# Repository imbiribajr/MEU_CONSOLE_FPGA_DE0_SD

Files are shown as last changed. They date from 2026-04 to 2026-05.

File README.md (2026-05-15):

# MEU_CONSOLE_FPGA_DE0_SD

Console de games em FPGA baseado em **Nios II**, com **launcher residente em flash NOR**, jogos carregados a partir de **cartão SD**, entrada por **teclado PS/2** e suporte a controle via **UART/Bluetooth**.

English version: [README.en.md](./README.en.md)

O projeto foi desenvolvido para a família **Intel/Altera Cyclone III** usando **Quartus II 13.0 SP1** e **Nios II EDS 13.0 SP1**. O hardware integra CPU Nios II, SDRAM, interface PS/2, UART, SPI para SD card, controlador de flash paralela e saída para matriz de LED.

## Visao Geral

Ao energizar a placa:

1. a FPGA carrega o hardware
2. o Nios II inicia um bootloader mínimo em memória on-chip
3. esse bootloader lê o `launcher` gravado na flash NOR
4. o `launcher` sobe em SDRAM
5. o `launcher` monta FAT32 no cartão SD
6. os jogos `.gmod` são listados no menu
7. o jogo selecionado é carregado para SDRAM e executado

## Principais Recursos

- Boot autônomo do sistema sem depender de `nios2-download`
- `launcher` persistido em flash paralela
- Jogos armazenados no SD em formato `.gmod`
- Navegacão por teclado **PS/2**
- Controle alternativo via **UART** para módulo Bluetooth/controller serial
- Renderização em **matriz LED HUB75**
- Uso de **SDRAM** para execução do launcher e dos jogos
- Infraestrutura para atualizar launcher, boot e jogos separadamente

## Fotos

Pac-Man rodando na matriz LED com a placa em primeiro plano:

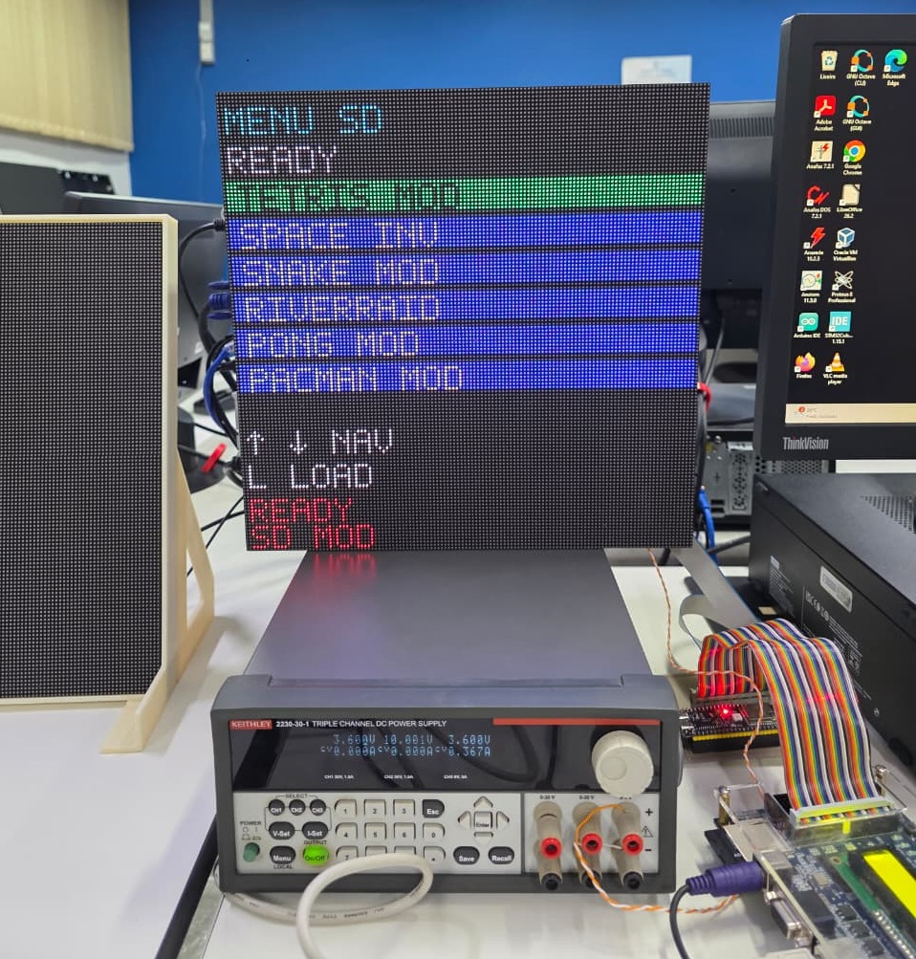
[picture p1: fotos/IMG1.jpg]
Plataforma matriz LED


Launcher em execução com seleção de jogos no SD e controle Bluetooth via UART:

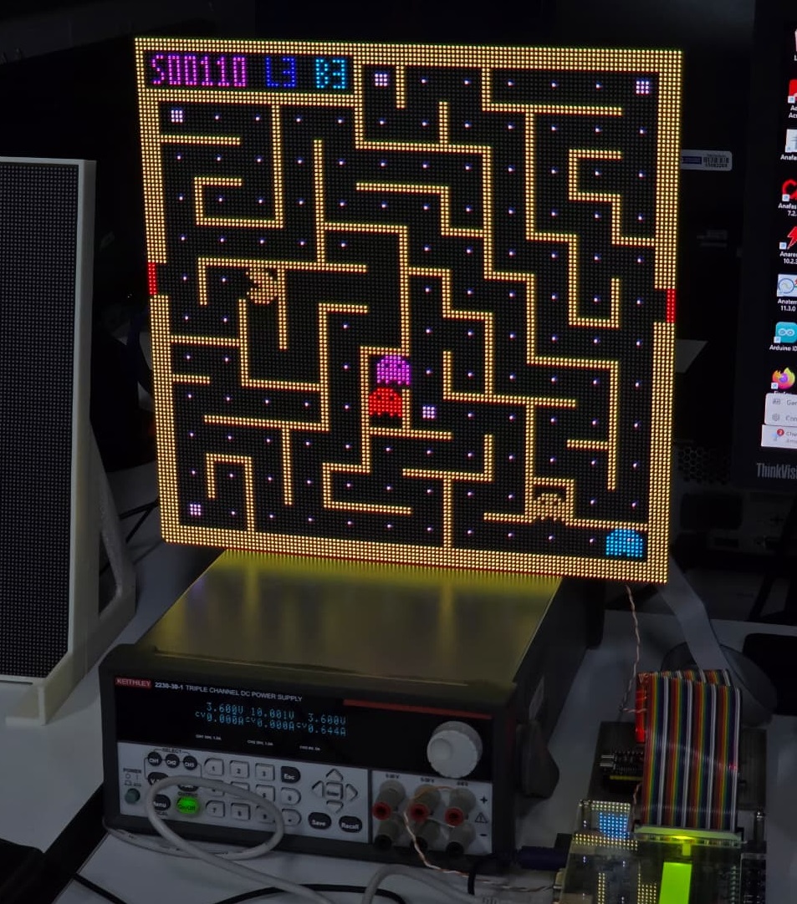
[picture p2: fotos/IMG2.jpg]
Launcher com controle Bluetooth


## Hardware

O hardware principal está em [`hardware/`](./hardware) e usa como topo o arquivo [`hardware/Hardware.vhd`](./hardware/Hardware.vhd).

Blocos relevantes presentes no projeto:

- **Nios II Qsys** gerado em `hardware/NiosII_ps2/`
- **PS/2** via `ps2_avalon_interface.vhd`
- **UART** para recepção de comandos seriais/Bluetooth
- **SPI SD card** para leitura dos jogos no SD
- **Flash NOR paralela** para armazenamento do launcher
- **SDRAM** como memória principal de execução
- **Matriz LED** controlada por `led_matrix_avalon.vhd`

Projeto Quartus:

- arquivo de projeto: [`hardware/DriverVHDL.qpf`](./hardware/DriverVHDL.qpf)
- constraints e pinagem: [`hardware/DriverVHDL.qsf`](./hardware/DriverVHDL.qsf)

## Arquitetura De Software

O software está organizado em três camadas principais:

- **flashboot**
  Bootloader mínimo executado a partir da memória on-chip. Carrega o launcher da NOR para SDRAM.
- **flashwrite**
  Aplicativo utilitário que grava ou atualiza a imagem do launcher na flash paralela.
- **launcher**
  Menu principal que monta FAT32 no SD, lista os jogos e carrega arquivos `.gmod`.

Pastas principais:

- [`software/bsp/`](./software/bsp): BSP gerado pelo Nios II EDS
- [`software/games/flashboot/`](./software/games/flashboot): bootloader
- [`software/games/flashwrite/`](./software/games/flashwrite): gravação da imagem do launcher na NOR
- [`software/games/launcher/`](./software/games/launcher): launcher e módulos de jogo
- [`software/scripts/`](./software/scripts): scripts auxiliares de build e programação
- [`software/workspace/`](./software/workspace): área de app Nios usada no fluxo de desenvolvimento

## Fluxo De Boot

Fluxo validado no projeto:

1. o Nios II sai do reset na memória on-chip
2. o `flashboot` é executado
3. a flash NOR é estabilizada e colocada em `read array`
4. o header `LNCH` do launcher é validado
5. o payload do launcher é copiado para SDRAM
6. `gp`, `sp` e `entry` são ajustados
7. a execução é transferida ao launcher
8. o launcher monta o SD FAT32 e lista os jogos

Documentação de apoio:

- [`software/games/flashboot/BOOT_FLOW.md`](./software/games/flashboot/BOOT_FLOW.md)
- [`software/games/flashboot/README.md`](./software/games/flashboot/README.md)
- [`software/games/flashwrite/README.md`](./software/games/flashwrite/README.md)

## Formato Dos Jogos

Os jogos atuais no SD usam arquivos binários `.gmod`.

Características do formato atual:

- múltiplos segmentos carregáveis
- `entry_addr`, `stack_addr` e `gp_addr` no cabeçalho
- carga direta em SDRAM pelo launcher

Definições:

- [`software/games/launcher/app/launcher_image.h`](./software/games/launcher/app/launcher_image.h)
- gerador: [`software/scripts/gerar_gmod.ps1`](./software/scripts/gerar_gmod.ps1)

Jogos atualmente presentes no repositório:

- Arkanoid
- Boulder Dash (`gdash`)
- Pac-Man
- Pong
- River Raid
- Snake
- Space Invaders
- Tetris

Os binários prontos de exemplo estão em:

- [`software/games/launcher/app/gmods/`](./software/games/launcher/app/gmods)

## Controles

O launcher aceita entrada por:

- **PS/2**
- **UART**
- botões locais mapeados no PIO

No launcher, o mapeamento principal é:

- `Up/Down`: navegar no menu
- `L`, `Enter`, `Space` ou equivalente serial: selecionar/carregar

Nos jogos, o código mostra leitura combinada de:

- scan codes de **PS/2**
- bytes recebidos pela **UART**

Isso permite usar teclado PS/2 ou um controle Bluetooth que entrega comandos seriais à UART do sistema.

A qualquer momento o sistema aceita os seguintes comandos:

- sw0 na DE0 reset o game
- button2 na DE0 recarrega o launcher. Permite o usuário chamar o launcher para carregar novo game

## Como Compilar

### Requisitos

- Quartus II **13.0 SP1**
- Nios II EDS **13.0 SP1**
- Windows com acesso ao `Nios_Shell.bat`
- Cabo **USB-Blaster**

Caminhos usados nos scripts atuais:

- `F:\altera\13.0sp1\quartus`
- `F:\altera\13.0sp1\nios2eds`

Se sua instalação estiver em outro local, ajuste os `.bat` e `.ps1` em [`software/scripts/`](./software/scripts) e nas configurações do VS Code em [`.vscode/settings.json`](./.vscode/settings.json).

### Hardware

Gerar Qsys:

```powershell
cd software\scripts
.\Generate_Qsys.bat
```

Sintetizar no Quartus:

```powershell
cd hardware
quartus_sh --flow compile DriverVHDL
```

Gravar FPGA:

```powershell
cd hardware\output_files
quartus_pgm -m jtag -c USB-Blaster -o "p;DriverVHDL.sof"
```

### BSP

Regenerar arquivos do BSP:

```powershell
cd software\bsp
nios2-bsp-generate-files --settings=settings.bsp --bsp-dir=.
```

Compilar BSP:

```powershell
cd software\scripts
.\compila_BSP.bat
```

### Launcher

Compilar e baixar o launcher para desenvolvimento:

```powershell
cd software\games\launcher\app
.\compila_grava.bat
```

### Geração da Imagem Do Launcher Para Flash

```powershell
powershell -ExecutionPolicy Bypass -File software\scripts\gerar_launcher_flash_image.ps1
```

Esse script gera:

- `software/games/launcher/app/launcher_flash.img`
- `software/games/flashwrite/app/launcher_flash_payload.h`

### Gravar O Launcher Na NOR

Depois de gerar a imagem:

1. compile o `flashwrite`
2. execute o `flashwrite` na placa
3. ele apaga, grava e verifica a imagem na flash

Documentação:

- [`software/games/flashwrite/README.md`](./software/games/flashwrite/README.md)

### Atualizar O Bootloader On-Chip

Sempre que o `flashboot` mudar:

1. compile `software/games/flashboot/app`
2. gere `hardware/onchip_mem.hex`
3. recompile o hardware Quartus para embutir o novo HEX no bitstream

Fluxo detalhado:

- [`software/games/flashboot/BOOT_FLOW.md`](./software/games/flashboot/BOOT_FLOW.md)

## Como Gerar Um Novo Jogo `.gmod`

Cada jogo externo possui um módulo próprio em:

- `software/games/launcher/app/<nome>_module/`

Normalmente cada módulo contém:

- `main.c`
- `external_main.c`
- `build_external.bat`

Exemplo de build de um jogo:

```powershell
cd software\games\launcher\app\pacman_module
.\build_external.bat
```

O `.gmod` resultante e salvo em:

- [`software/games/launcher/app/gmods/`](./software/games/launcher/app/gmods)

Documentação:

- [`software/games/launcher/EXTERNAL_BUILD.md`](./software/games/launcher/EXTERNAL_BUILD.md)

## Estrutura Do Repositório

```text
MEU_CONSOLE_FPGA_DE0_SD/
|- hardware/                      -> projeto Quartus e componentes HDL
|- software/
|  |- bsp/                        -> BSP do Nios II
|  |- games/
|  |  |- flashboot/               -> bootloader em on-chip
|  |  |- flashwrite/              -> gravação da imagem do launcher na NOR
|  |  |- launcher/                -> launcher e jogos
|  |- scripts/                    -> automação de build, flash e geração de imagens
|  |- workspace/                  -> app/workspace de desenvolvimento
|- .vscode/                       -> tasks e botões de ação do VS Code
```

## VS Code

O repositório inclui configuração para trabalhar com VS Code:

- botões de açao em [`.vscode/settings.json`](./.vscode/settings.json)
- tasks em [`.vscode/tasks.json`](./.vscode/tasks.json)
- debug em [`.vscode/launch.json`](./.vscode/launch.json)

O fluxo foi preparado para chamar o ambiente da Intel/Altera via `Nios_Shell.bat`.

## Estado Atual Do Projeto

Pelo estado atual do repositório:

- o hardware Quartus está presente e compilável
- o `flashboot` está integrado ao fluxo de boot
- o `launcher` carrega imagens `.gmod` do SD
- a leitura de FAT32 está implementada no próprio launcher
- os jogos já possuem módulos e artefatos `.gmod`
- o controle por PS/2 e UART está presente no launcher e nos jogos

## Observações

- O projeto inclui arquivos gerados do Qsys/synthesis que fazem parte do fluxo atual.
- Artefatos pesados de compilação do Quartus e objetos temporários do Nios estão filtrados pelo [`.gitignore`](./.gitignore).
- Alguns documentos internos ainda refletem fases anteriores do desenvolvimento; este README descreve o fluxo validado a partir do estado atual do código.

## Licença

Este projeto usa a licença [MIT](./LICENSE).

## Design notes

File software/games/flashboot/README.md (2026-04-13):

# Flashboot

Bootloader minimo que roda na on-chip e carrega o `launcher` da NOR para SDRAM.

## Estado Atual

Fluxo validado:

1. o Nios II sai do reset real em `0x0180C000`
2. o stub em `.reset` salta para `_start`
3. o `flashboot` roda na `onchip_memory2_0`
4. mostra `LOADING...`
5. espera a NOR estabilizar no power-on
6. forca `read array` com `0xF0`
7. le e valida o header `LNCH`
8. copia o payload do `launcher` para SDRAM
9. ajusta `gp/sp`
10. salta para `entry`

## Endereco Da Imagem Na NOR

O `flashboot` atual espera o `launcher` em:

- `FLASHBOOT_IMAGE_OFFSET = 0x010000`

## Arquivos Principais

- [main.c](./app/main.c)
- [linker_flashboot.x](./app/linker_flashboot.x)
- [flashboot_image.h](./app/flashboot_image.h)

## Scripts Relacionados

- gerar imagem do launcher:
  [gerar_launcher_flash_image.ps1](../../scripts/gerar_launcher_flash_image.ps1)
- gerar `onchip_mem.hex`:
  [gerar_onchip_hex.bat](./app/gerar_onchip_hex.bat)

## Documentacao Completa

- [BOOT_FLOW.md](./BOOT_FLOW.md)

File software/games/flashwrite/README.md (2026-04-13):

# Flashwrite

Aplicativo utilitario para gravar a imagem `LNCH` do `launcher` na NOR.

## Fluxo Atual

1. gerar a imagem do launcher:
   - `software/scripts/gerar_launcher_flash_image.ps1`
2. isso atualiza:
   - `software/games/flashwrite/app/launcher_flash_payload.h`
3. compilar o `flashwrite`:
   - `software/games/flashwrite/app/compila_grava.bat`
4. executar o `flashwrite`
5. o app:
   - apaga
   - programa
   - verifica

## Mapeamento Validado

No fluxo final estabilizado:

- a imagem do launcher e gravada a partir de `0x010000`
- a geometria efetiva tratada pelo software usa setores de `0x8000`
- o espaco efetivo usado pelo software ficou em `2 MB`

## Arquivos Principais

- [main.c](./app/main.c)
- [launcher_flash_payload.h](./app/launcher_flash_payload.h)

## Relacao Com O Boot

Depois de gravar a NOR com sucesso, o `flashboot` pode carregar o `launcher` automaticamente no power-on.

Fluxo completo:

- [BOOT_FLOW.md](../flashboot/BOOT_FLOW.md)

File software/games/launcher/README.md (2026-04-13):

# Launcher

Launcher principal da plataforma.

## Arquitetura Atual

No fluxo final validado:

1. o `flashboot` sobe da on-chip
2. o `launcher` e carregado da NOR para SDRAM
3. o `launcher` monta FAT32 no SD
4. o menu enumera os jogos em `games/*.gmod`
5. o `launcher` carrega a imagem externa para SDRAM e salta para o jogo

## Formato De Jogo No SD

Os jogos no SD sao armazenados como arquivos binarios `.gmod`.

Campos principais:

- `version = 2`
- `segment_count`
- `entry_addr`
- `stack_addr`
- `gp_addr`
- `header_size`
- `title[32]`

Depois do cabecalho vem a tabela de segmentos e o payload binario.

## Geracao Dos `.gmod`

O fluxo correto nao usa mais diretamente o `main.elf` standalone antigo de desenvolvimento.

O `.gmod` final deve ser gerado a partir dos modulos de producao em:

- `software/games/launcher/app/*_module/`

Cada jogo externo usa:

- `main.c`
- `external_main.c`
- `build_external.bat`

Os `.gmod` gerados ficam em:

- `software/games/launcher/app/gmods/`

Documentacao detalhada:

- [EXTERNAL_BUILD.md](./EXTERNAL_BUILD.md)

## Arquivos Principais

- [main.c](./app/main.c)
- [launcher_image.h](./app/launcher_image.h)
- [launcher_storage_stub.c](./app/launcher_storage_stub.c)

## Relacao Com O Boot

O fluxo de boot automatico completo foi consolidado em:

- [BOOT_FLOW.md](../flashboot/BOOT_FLOW.md)

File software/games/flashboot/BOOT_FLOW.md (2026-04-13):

# Boot Flow Do Launcher

Este documento descreve a cadeia real de boot da plataforma, do power-on ate o launcher aparecer no display.

## Objetivo

Ao ligar a placa:

1. a FPGA configura o hardware
2. o Nios II entra no `flashboot`
3. o `flashboot` carrega o `launcher` da flash paralela para a SDRAM
4. o `launcher` sobe
5. o `launcher` lista e executa os jogos do SD

## Blocos Do Sistema

- `launcher`
  Menu principal. Roda em SDRAM e carrega jogos binarios `.gmod` do SD.

- `flashwrite`
  Aplicativo utilitario que grava a imagem empacotada do `launcher` no inicio da flash paralela.

- `flashboot`
  Bootloader minimo que roda na `onchip_memory2_0`, le a imagem do `launcher` da flash paralela, copia para SDRAM e transfere a execucao.

## Estado Validado

### Flash paralela

A flash paralela conectada ao `generic_tristate_controller_0` em `0x01400000` foi validada:

- leitura simples OK
- `CFI QRY` OK
- erase OK
- program OK
- readback OK

Conclusao: a interface com a NOR esta funcional.

### Launcher

O `launcher` ja esta funcional:

- inicializa a plataforma
- acessa o SD
- monta FAT32
- enumera jogos
- mostra o menu no display
- executa jogos binarios do SD e ainda aceita descritores texto legados como fallback

### Flashboot

O `flashboot` ja foi validado manualmente com `nios2-download -g`:

- ele le a imagem da flash
- copia o payload para SDRAM
- ajusta `gp` e `sp`
- salta para o `entry`
- o `launcher` sobe corretamente

## Ponto Critico Descoberto

O boot automatico falhava por dois motivos distintos.

### 1. Diferenca entre reset real e entry point do ELF

No boot real, o Nios II comeca no reset vector configurado no hardware:

- `0x0180C000`

No `nios2-download -g`, a execucao comeca no `_start` do ELF:

- `0x0180C040`

Sem um codigo explicito em `0x0180C000`, o power-on nao chegava ao `flashboot`, mesmo com o ELF correto.

### 2. Flash paralela ainda nao pronta no power-on

Depois que o stub de reset foi corrigido, ainda havia falha no power-on porque a NOR podia nao estar pronta na primeira leitura logo apos a configuracao da FPGA.

Isso foi resolvido no `flashboot` com:

- atraso inicial curto
- comando `0xF0` para forcar `read array`
- retries de leitura/validacao do header

Conclusao: o boot automatico correto depende tanto do stub de reset quanto da robustez na primeira leitura da NOR.

## Fluxo Real De Boot

Sequencia completa:

1. a FPGA carrega o bitstream
2. a `onchip_memory2_0` sobe inicializada com `onchip_mem.hex`
3. o Nios II sai do reset em `0x0180C000`
4. o stub em `.reset` salta para `_start`
5. o `flashboot` inicializa o display e mostra `LOADING...`
6. o `flashboot` espera a NOR estabilizar
7. o `flashboot` envia `0xF0` para garantir `read array`
8. o `flashboot` le e valida o header `LNCH` na flash
9. o `flashboot` copia o payload do `launcher` para SDRAM
10. o `flashboot` ajusta `gp` e `sp`
11. o `flashboot` salta para o `entry` do `launcher`
12. o `launcher` sobe e passa a operar normalmente

## Enderecos Importantes

- flash paralela:
  `GENERIC_TRISTATE_CONTROLLER_0_BASE = 0x01400000`

- on-chip do boot:
  `ONCHIP_MEMORY2_0_BASE = 0x0180C000`

- reset real do Nios II:
  `NIOS2_RESET_ADDR = 0x0180C000`

- exception vector:
  `NIOS2_EXCEPTION_ADDR = 0x0180C020`

- `_start` atual do `flashboot`:
  `0x0180C040`

## Arquitetura Da Imagem Na Flash

O `flashboot` espera uma imagem `LNCH` no inicio da flash paralela.

Header:

```c
typedef struct flashboot_image_header {
    uint32_t magic;
    uint32_t version;
    uint32_t load_addr;
    uint32_t entry_addr;
    uint32_t gp_addr;
    uint32_t sp_addr;
    uint32_t payload_size;
    uint32_t payload_checksum;
} flashboot_image_header_t;
```

Campos principais:

- `magic = 'LNCH'`
- `version = 1`
- `load_addr = endereco de carga do launcher na SDRAM`
- `entry_addr = entry do launcher`
- `gp_addr = gp do launcher`
- `sp_addr = sp do launcher`
- `payload_size = tamanho do binario`
- `payload_checksum = soma simples dos bytes`

Depois do header vem o payload bruto do `launcher`.

## Cadeia Necessaria Para O Launcher Correto

Para o boot automatico funcionar de forma consistente, toda a cadeia abaixo precisa estar alinhada.

### 1. Launcher compilado

O `launcher` precisa ser compilado normalmente.

Artefato principal:

- `software/games/launcher/app/main.elf`

### 2. Imagem LNCH gerada

O script:

- [gerar_launcher_flash_image.ps1](../../scripts/gerar_launcher_flash_image.ps1)

gera:

- [launcher_flash.img](../launcher/app/launcher_flash.img)
- [launcher_flash_payload.h](../flashwrite/app/launcher_flash_payload.h)

Essa imagem precisa corresponder ao `launcher` que voce quer subir no boot.

### 3. Launcher gravado na flash paralela

O `flashwrite` usa:

- [main.c](../flashwrite/app/main.c)
- [launcher_flash_payload.h](../flashwrite/app/launcher_flash_payload.h)

para:

1. apagar os setores iniciais
2. programar a imagem `LNCH`
3. verificar byte a byte

O resultado esperado e:

- `flashwrite: OK`

### 4. Flashboot compilado com stub de reset

O `flashboot` precisa conter o stub explicito em `.reset`:

```c
void flashboot_reset_stub(void) __attribute__((section(".reset"), naked));
void flashboot_reset_stub(void)
{
    __asm__ __volatile__(
        "movia r2, _start\n"
        "jmp r2\n"
    );
}
```

Esse stub garante que o boot real iniciado em `0x0180C000` chegue ao `_start`.

### 5. Linker do flashboot apontando para a on-chip

O linker do `flashboot` precisa manter:

- memoria `onchip` com origem em `0x0180C000`
- secao `.reset` mantida no inicio dessa memoria

Arquivo:

- [linker_flashboot.x](./app/linker_flashboot.x)

### 6. Robustez de power-on na leitura da NOR

O `flashboot` validado agora contem:

- atraso inicial de power-up
- `flash_reset_read_array()`
- retries de leitura/validacao do header

Isso e necessario porque o boot real ocorre imediatamente apos a configuracao, ao contrario do `nios2-download`.

### 7. `onchip_mem.hex` gerado a partir do flashboot correto

Depois de compilar o `flashboot`, e preciso gerar:

- [hardware/onchip_mem.hex](../../../hardware/onchip_mem.hex)

com:

- [gerar_onchip_hex.bat](./app/gerar_onchip_hex.bat)

Esse passo tambem atualiza:

- [NiosII_ps2_onchip_memory2_0.hex](../../../hardware/NiosII_ps2/synthesis/submodules/NiosII_ps2_onchip_memory2_0.hex)

### 8. Hardware recompilado usando esse HEX

O Qsys precisa continuar apontando para:

- `resetSlave = onchip_memory2_0.s1`
- `exceptionSlave = onchip_memory2_0.s1`
- `initializationFileName = onchip_mem.hex`

Depois disso, o hardware Quartus precisa ser recompilado para embutir o novo conteudo da on-chip no bitstream.

### 9. Bitstream final gravado na FPGA / serial flash

O `.sof` ou `.pof` final precisa conter:

- o hardware atual
- o `onchip_mem.hex` gerado a partir do `flashboot` correto

Sem esse passo, a placa pode continuar iniciando com um `flashboot` antigo mesmo que a NOR ja tenha sido atualizada.

## Sequencia Operacional Correta

Use esta ordem quando quiser atualizar o boot completo da plataforma.

### 1. Recompilar o launcher

No PowerShell:

```powershell
cd F:\Jogos_FPGA\MEU_CONSOLE_FPGA_DE0_SD\software\games\launcher\app
.\compila_grava.bat
```

### 2. Regenerar a imagem do launcher para a NOR

```powershell
powershell -ExecutionPolicy Bypass -File "F:\Jogos_FPGA\MEU_CONSOLE_FPGA_DE0_SD\software\scripts\gerar_launcher_flash_image.ps1"
```

Isso atualiza:

- `software/games/launcher/app/launcher_flash.img`
- `software/games/flashwrite/app/launcher_flash_payload.h`

### 3. Recompilar o flashwrite

```powershell
cd F:\Jogos_FPGA\MEU_CONSOLE_FPGA_DE0_SD\software\games\flashwrite\app
.\compila_grava.bat
```

### 4. Gravar a NOR com o launcher

Execute o `flashwrite` e espere terminar com:

- `flashwrite: OK`

No fluxo atual validado, o `launcher` e gravado a partir de:

- `0x010000`

### 5. Recompilar o flashboot

```powershell
cd F:\Jogos_FPGA\MEU_CONSOLE_FPGA_DE0_SD\software\games\flashboot\app
.\compila_grava.bat
```

### 6. Regenerar o onchip_mem.hex

Ainda dentro de `flashboot/app`:

```powershell
.\gerar_onchip_hex.bat
```

### 7. Recompilar o hardware no Quartus

Depois do `onchip_mem.hex` novo, recompile o projeto Quartus para embutir o `flashboot` atualizado na on-chip.

### 8. Carregar o .sof novo na FPGA

Para teste rapido, basta gravar o `.sof` novo por JTAG. Nao e necessario gravar o `.pof` ainda.

### 9. Preparar o SD

No SD devem estar:

- os jogos `.gmod` binarios reais em `games/`

O `launcher` nao precisa ir para o SD nesse fluxo, porque ele ja esta na NOR.

Observacao importante sobre os jogos:

- o `.gmod` binario deve ser gerado a partir de um ELF compativel com o ambiente do `launcher`
- nao use diretamente o ELF standalone de desenvolvimento sem validar compatibilidade
- a base mais segura para gerar esses ELFs e o codigo ja adaptado dentro de:
  - `software/games/launcher/app/pacman_module/`
  - `software/games/launcher/app/tetris_module/`
  - e equivalentes para outros jogos
- em outras palavras, o `main.c` usado como entrada de compilacao para o ELF externo deve vir das pastas `*_module` do `launcher`, ou de uma versao externa derivada delas, e nao do fluxo antigo de desenvolvimento isolado

### 10. Testar o power-on

Fluxo esperado:

1. a FPGA sobe com o `flashboot` novo
2. o `flashboot` le o `launcher` em `0x010000` da NOR
3. o `launcher` sobe
4. o `launcher` carrega os jogos do SD

### 11. So depois gerar/gravar o .pof

Se o teste com `.sof` por JTAG funcionar, ai sim faz sentido fechar o processo com o `.pof` definitivo na serial flash.

Nao basta gerar o novo `onchip_mem.hex`.

E preciso garantir que o `.sof` ou `.pof` realmente gravado na placa foi gerado depois dessa atualizacao.

Se o arquivo de configuracao gravado for antigo, o Nios continuara usando uma on-chip antiga no power-on.

## Sequencia Pratica Recomendada

Fluxo completo para fechar o launcher correto:

1. compilar o `launcher`
2. rodar `gerar_launcher_flash_image.ps1`
3. gravar a imagem do `launcher` na NOR com `flashwrite`
4. compilar o `flashboot`
5. rodar `gerar_onchip_hex.bat`
6. recompilar o hardware Quartus
7. gerar o `.sof` ou `.pof`
8. gravar o arquivo final de configuracao na FPGA ou serial flash
9. energizar a placa e observar `LOADING...`
10. confirmar a subida automatica do `launcher`

## Diagnostico Esperado

### Se tudo estiver correto

No power-on:

- `LOADING...` aparece imediatamente
- o `launcher` sobe sem `nios2-download`

### Se `LOADING...` nao aparecer

O problema tende a estar antes do acesso a flash:

- bitstream antigo
- `onchip_mem.hex` antigo embutido no hardware
- reset vector nao atingindo o `flashboot`

### Se `LOADING...` aparecer mas o launcher nao subir

O problema tende a estar depois da entrada no `flashboot`:

- imagem `LNCH` nao gravada corretamente
- header invalido
- payload inconsistente
- falha de leitura da NOR

## Atualizacao De Jogos Depois Disso

Modelo desejado:

- flash paralela guarda o `launcher`
- SD guarda os jogos

Entao:

- mudar jogo no SD nao exige reflashing da NOR
- mudar o `launcher` exige regenerar a imagem e regravar a NOR

## Arquivos Principais

### Flashboot

- [main.c](./app/main.c)
- [flashboot_image.h](./app/flashboot_image.h)
- [linker_flashboot.x](./app/linker_flashboot.x)
- [gerar_onchip_hex.bat](./app/gerar_onchip_hex.bat)

### Gravacao Da NOR

- [main.c](../flashwrite/app/main.c)
- [launcher_flash_payload.h](../flashwrite/app/launcher_flash_payload.h)
- [gerar_launcher_flash_image.ps1](../../scripts/gerar_launcher_flash_image.ps1)

### Launcher

- [main.c](../launcher/app/main.c)

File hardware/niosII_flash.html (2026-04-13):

niosII_flash

2026.03.27.23:20:15 | Datasheet

Overview

clk_0 | niosII_flash

clk_audio

Processor
nios2_qsys_0 Nios II 13.0
All Components
nios2_qsys_0 altera_nios2_qsys 13.0
onchip_memory2_0 altera_avalon_onchip_memory2 13.0.1.99.2
jtag_uart_0 altera_avalon_jtag_uart 13.0.1.99.2
pio_0 altera_avalon_pio 13.0.1.99.2
led_matrix_avalon_0 led_matrix_avalon 1.0
sysid_qsys_0 altera_avalon_sysid_qsys 13.0
ps2_interface_0 ps2_interface 1.0
new_sdram_controller_0 altera_avalon_new_sdram_controller 13.0.1.99.2
audio AUDIO_IF 2.0
i2c_clk altera_avalon_pio 13.0.1.99.2
i2c_sda altera_avalon_pio 13.0.1.99.2
timer_0 altera_avalon_timer 13.0.1.99.2
generic_tristate_controller_0 altera_generic_tristate_controller 13.0

Memory Map

| nios2_qsys_0
| data_master | instruction_master
nios2_qsys_0
jtag_debug_module | 0x01810800 | 0x01810800
onchip_memory2_0
s1 | 0x0180c000 | 0x0180c000
jtag_uart_0
avalon_jtag_slave | 0x018110f8 | 0x018110f8
pio_0
s1 | 0x018110d0 | 0x018110d0
led_matrix_avalon_0
avalon_slave | 0x01808000 | 0x01808000
sysid_qsys_0
control_slave | 0x018110f0 | 0x018110f0
ps2_interface_0
avalon_slave_0 | 0x01811104 | 0x01811104
new_sdram_controller_0
s1 | 0x00800000 | 0x00800000
audio
avalon_slave | 0x01811060 | 0x01811060
i2c_clk
s1 | 0x018110c0 | 0x018110c0
i2c_sda
s1 | 0x018110b0 | 0x018110b0
timer_0
s1 | 0x01811040 | 0x01811040
generic_tristate_controller_0
uas | 0x01400000 | 0x01400000

## clk_0

clock_source v13.0

Parameters

clockFrequency | 50000000
clockFrequencyKnown | true
inputClockFrequency | 0
resetSynchronousEdges | NONE
deviceFamily | UNKNOWN
generateLegacySim | false

Software Assignments
(none)

## nios2_qsys_0

altera_nios2_qsys v13.0

clk_0 | clk | nios2_qsys_0
| clk
| clk_reset
| reset_n
| | | instruction_master | onchip_memory2_0
| | | s1
| | | data_master
| | | s1
| | | jtag_debug_module_reset
| | | reset1
| | | data_master | jtag_uart_0
| | | avalon_jtag_slave
| | | d_irq
| | | irq
| | | jtag_debug_module_reset
| | | reset
| | | instruction_master
| | | avalon_jtag_slave
| | | data_master | pio_0
| | | s1
| | | jtag_debug_module_reset
| | | reset
| | | instruction_master
| | | s1
| | | data_master | led_matrix_avalon_0
| | | avalon_slave
| | | jtag_debug_module_reset
| | | reset_n
| | | instruction_master
| | | avalon_slave
| | | data_master | sysid_qsys_0
| | | control_slave
| | | instruction_master
| | | control_slave
| | | jtag_debug_module_reset
| | | reset
| | | data_master | ps2_interface_0
| | | avalon_slave_0
| | | jtag_debug_module_reset
| | | reset
| | | instruction_master
| | | avalon_slave_0
| | | instruction_master | new_sdram_controller_0
| | | s1
| | | data_master
| | | s1
| | | jtag_debug_module_reset
| | | reset
| | | data_master | audio
| | | avalon_slave
| | | instruction_master
| | | avalon_slave
| | | jtag_debug_module_reset
| | clock_sink_reset
| | data_master | i2c_clk
| | s1
| | instruction_master
| | s1
| | jtag_debug_module_reset
| | reset
| | jtag_debug_module_reset | i2c_sda
| | reset
| | instruction_master
| | s1
| | data_master
| | s1
| | jtag_debug_module_reset | clk_audio
| | clk_in_reset
| | jtag_debug_module_reset | timer_0
| | reset
| | instruction_master
| | s1
| | data_master
| | s1
| | d_irq
| | irq
| | jtag_debug_module_reset | generic_tristate_controller_0
| | reset
| | instruction_master
| | uas
| | data_master
| | uas

Parameters

setting_showUnpublishedSettings | false
setting_showInternalSettings | false
setting_preciseSlaveAccessErrorException | false
setting_preciseIllegalMemAccessException | false
setting_preciseDivisionErrorException | false
setting_performanceCounter | false
setting_illegalMemAccessDetection | false
setting_illegalInstructionsTrap | false
setting_fullWaveformSignals | false
setting_extraExceptionInfo | false
setting_exportPCB | false
setting_debugSimGen | false
setting_clearXBitsLDNonBypass | true
setting_bit31BypassDCache | true
setting_bigEndian | false
setting_export_large_RAMs | false
setting_asic_enabled | false
setting_asic_synopsys_translate_on_off | false
setting_oci_export_jtag_signals | false
setting_bhtIndexPcOnly | false
setting_avalonDebugPortPresent | false
setting_alwaysEncrypt | true
setting_allowFullAddressRange | false
setting_activateTrace | true
setting_activateTestEndChecker | false
setting_activateMonitors | true
setting_activateModelChecker | false
setting_HDLSimCachesCleared | true
setting_HBreakTest | false
muldiv_divider | true
mpu_useLimit | false
mpu_enabled | false
mmu_enabled | false
mmu_autoAssignTlbPtrSz | true
manuallyAssignCpuID | true
debug_triggerArming | true
debug_embeddedPLL | true
debug_debugReqSignals | false
debug_assignJtagInstanceID | false
dcache_omitDataMaster | false
cpuReset | false
is_hardcopy_compatible | false
setting_shadowRegisterSets | 0
mpu_numOfInstRegion | 8
mpu_numOfDataRegion | 8
mmu_TLBMissExcOffset | 0
debug_jtagInstanceID | 0
resetOffset | 0
exceptionOffset | 32
cpuID | 0
cpuID_stored | 0
breakOffset | 32
userDefinedSettings
resetSlave | onchip_memory2_0.s1
mmu_TLBMissExcSlave | None
exceptionSlave | onchip_memory2_0.s1
breakSlave | nios2_qsys_0.jtag_debug_module
setting_perfCounterWidth | 32
setting_interruptControllerType | Internal
setting_branchPredictionType | Automatic
setting_bhtPtrSz | 8
muldiv_multiplierType | EmbeddedMulFast
mpu_minInstRegionSize | 12
mpu_minDataRegionSize | 12
mmu_uitlbNumEntries | 4
mmu_udtlbNumEntries | 6
mmu_tlbPtrSz | 7
mmu_tlbNumWays | 16
mmu_processIDNumBits | 8
impl | Fast
icache_size | 4096
icache_tagramBlockType | Automatic
icache_ramBlockType | Automatic
icache_numTCIM | 0
icache_burstType | None
dcache_bursts | false
dcache_victim_buf_impl | ram
debug_level | Level1
debug_OCIOnchipTrace | _128
dcache_size | 2048
dcache_tagramBlockType | Automatic
dcache_ramBlockType | Automatic
dcache_numTCDM | 0
dcache_lineSize | 32
setting_exportvectors | false
setting_ecc_present | false
regfile_ramBlockType | Automatic
ocimem_ramBlockType | Automatic
mmu_ramBlockType | Automatic
bht_ramBlockType | Automatic
resetAbsoluteAddr | 25214976
exceptionAbsoluteAddr | 25215008
breakAbsoluteAddr | 25233440
mmu_TLBMissExcAbsAddr | 0
dcache_bursts_derived | false
dcache_size_derived | 2048
dcache_lineSize_derived | 32
translate_on | "synthesis translate_on"
translate_off | "synthesis translate_off"
instAddrWidth | 25
dataAddrWidth | 25
tightlyCoupledDataMaster0AddrWidth | 1
tightlyCoupledDataMaster1AddrWidth | 1
tightlyCoupledDataMaster2AddrWidth | 1
tightlyCoupledDataMaster3AddrWidth | 1
tightlyCoupledInstructionMaster0AddrWidth | 1
tightlyCoupledInstructionMaster1AddrWidth | 1
tightlyCoupledInstructionMaster2AddrWidth | 1
tightlyCoupledInstructionMaster3AddrWidth | 1

instSlaveMapParam

<address-map><slave name='new_sdram_controller_0.s1' start='0x800000' end='0x1000000' /><slave name='generic_tristate_controller_0.uas' start='0x1400000' end='0x1800000' /><slave name='led_matrix_avalon_0.avalon_slave' start='0x1808000' end='0x180C000' /><slave name='onchip_memory2_0.s1' start='0x180C000' end='0x1810000' /><slave name='nios2_qsys_0.jtag_debug_module' start='0x1810800' end='0x1811000' /><slave name='timer_0.s1' start='0x1811040' end='0x1811060' /><slave name='audio.avalon_slave' start='0x1811060' end='0x1811080' /><slave name='i2c_sda.s1' start='0x18110B0' end='0x18110C0' /><slave name='i2c_clk.s1' start='0x18110C0' end='0x18110D0' /><slave name='pio_0.s1' start='0x18110D0' end='0x18110E0' /><slave name='sysid_qsys_0.control_slave' start='0x18110F0' end='0x18110F8' /><slave name='jtag_uart_0.avalon_jtag_slave' start='0x18110F8' end='0x1811100' /><slave name='ps2_interface_0.avalon_slave_0' start='0x1811104' end='0x1811108' /></address-map>

dataSlaveMapParam

<address-map><slave name='new_sdram_controller_0.s1' start='0x800000' end='0x1000000' /><slave name='generic_tristate_controller_0.uas' start='0x1400000' end='0x1800000' /><slave name='led_matrix_avalon_0.avalon_slave' start='0x1808000' end='0x180C000' /><slave name='onchip_memory2_0.s1' start='0x180C000' end='0x1810000' /><slave name='nios2_qsys_0.jtag_debug_module' start='0x1810800' end='0x1811000' /><slave name='timer_0.s1' start='0x1811040' end='0x1811060' /><slave name='audio.avalon_slave' start='0x1811060' end='0x1811080' /><slave name='i2c_sda.s1' start='0x18110B0' end='0x18110C0' /><slave name='i2c_clk.s1' start='0x18110C0' end='0x18110D0' /><slave name='pio_0.s1' start='0x18110D0' end='0x18110E0' /><slave name='sysid_qsys_0.control_slave' start='0x18110F0' end='0x18110F8' /><slave name='jtag_uart_0.avalon_jtag_slave' start='0x18110F8' end='0x1811100' /><slave name='ps2_interface_0.avalon_slave_0' start='0x1811104' end='0x1811108' /></address-map>
clockFrequency | 50000000
deviceFamilyName | CYCLONEII
internalIrqMaskSystemInfo | 3
customInstSlavesSystemInfo | <info/>

deviceFeaturesSystemInfo

ADDRESS_STALL 1 CELL_LEVEL_BACK_ANNOTATION_DISABLED 0 COMPILER_SUPPORT 1 DSP 0 DSP_SHIFTER_BLOCK 0 DUMP_ASM_LAB_BITS_FOR_POWER 1 EMUL 1 ENABLE_ADVANCED_IO_ANALYSIS_GUI_FEATURES 0 EPCS 1 ESB 0 FAKE1 0 FAKE2 0 FAKE3 0 FAMILY_LEVEL_INSTALLATION_ONLY 1 FITTER_USE_FALLING_EDGE_DELAY 0 GENERATE_DC_ON_CURRENT_WARNING_FOR_INTERNAL_CLAMPING_DIODE 0 HARDCOPY 0 HAS_18_BIT_MULTS 0 HAS_ACE_SUPPORT 1 HAS_ADJUSTABLE_OUTPUT_IO_TIMING_MEAS_POINT 0 HAS_ADVANCED_IO_INVERTED_CORNER 0 HAS_ADVANCED_IO_POWER_SUPPORT 0 HAS_ADVANCED_IO_TIMING_SUPPORT 0 HAS_ALM_SUPPORT 0 HAS_ATOM_AND_ROUTING_POWER_MODELED_TOGETHER 0 HAS_AUTO_DERIVE_CLOCK_UNCERTAINTY_SUPPORT 0 HAS_AUTO_FIT_SUPPORT 1 HAS_BALANCED_OPT_TECHNIQUE_SUPPORT 1 HAS_BENEFICIAL_SKEW_SUPPORT 0 HAS_BITLEVEL_DRIVE_STRENGTH_CONTROL 0 HAS_BSDL_FILE_GENERATION 0 HAS_CGA_SUPPORT 1 HAS_CHECK_NETLIST_SUPPORT 1 HAS_CLOCK_REGION_CHECKER_ENABLED 1 HAS_CORE_JUNCTION_TEMP_DERATING 1 HAS_CROSSTALK_SUPPORT 0 HAS_CUSTOM_REGION_SUPPORT 1 HAS_DAP_JTAG_FROM_HPS 0 HAS_DATA_DRIVEN_ACVQ_HSSI_SUPPORT 0 HAS_DDB_FDI_SUPPORT 0 HAS_DESIGN_ANALYZER_SUPPORT 1 HAS_DETAILED_IO_RAIL_POWER_MODEL 1 HAS_DETAILED_LEIM_STATIC_POWER_MODEL 0 HAS_DETAILED_LE_POWER_MODEL 1 HAS_DETAILED_ROUTING_MUX_STATIC_POWER_MODEL 0 HAS_DETAILED_THERMAL_CIRCUIT_PARAMETER_SUPPORT 1 HAS_DEVICE_MIGRATION_SUPPORT 1 HAS_DIAGONAL_MIGRATION_SUPPORT 0 HAS_EMIF_TOOLKIT_SUPPORT 0 HAS_ERROR_DETECTION_SUPPORT 0 HAS_FAMILY_VARIANT_MIGRATION_SUPPORT 0 HAS_FANOUT_FREE_NODE_SUPPORT 1 HAS_FAST_FIT_SUPPORT 1 HAS_FITTER_EARLY_TIMING_ESTIMATE_SUPPORT 1 HAS_FITTER_ECO_SUPPORT 1 HAS_FIT_NETLIST_OPT_RETIME_SUPPORT 1 HAS_FIT_NETLIST_OPT_SUPPORT 1 HAS_FORMAL_VERIFICATION_SUPPORT 1 HAS_FPGA_XCHANGE_SUPPORT 1 HAS_FSAC_LUTRAM_REGISTER_PACKING_SUPPORT 0 HAS_FULL_DAT_MIN_TIMING_SUPPORT 1 HAS_FULL_INCREMENTAL_DESIGN_SUPPORT 1 HAS_FUNCTIONAL_SIMULATION_SUPPORT 1 HAS_FUNCTIONAL_VERILOG_SIMULATION_SUPPORT 0 HAS_FUNCTIONAL_VHDL_SIMULATION_SUPPORT 0 HAS_GLITCH_FILTERING_SUPPORT 1 HAS_HC_READY_SUPPORT 0 HAS_HIGH_SPEED_LOW_POWER_TILE_SUPPORT 0 HAS_HOLD_TIME_AVOIDANCE_ACROSS_CLOCK_SPINE_SUPPORT 1 HAS_HSPICE_WRITER_SUPPORT 0 HAS_HSSI_POWER_CALCULATOR 0 HAS_IBISO_WRITER_SUPPORT 1 HAS_INCREMENTAL_DAT_SUPPORT 0 HAS_INCREMENTAL_SYNTHESIS_SUPPORT 1 HAS_INTERFACE_PLANNER_SUPPORT 0 HAS_IO_ASSIGNMENT_ANALYSIS_SUPPORT 1 HAS_IO_DECODER 0 HAS_IO_PLACEMENT_OPTIMIZATION_SUPPORT 1 HAS_IO_SMART_RECOMPILE_SUPPORT 1 HAS_JITTER_SUPPORT 0 HAS_JTAG_SLD_HUB_SUPPORT 1 HAS_LIMITED_TCL_FITTER_SUPPORT 0 HAS_LOGIC_LOCK_SUPPORT 1 HAS_MICROPROCESSOR 0 HAS_MIF_SMART_COMPILE_SUPPORT 1 HAS_MINMAX_TIMING_MODELING_SUPPORT 0 HAS_MIN_TIMING_ANALYSIS_SUPPORT 1 HAS_MUX_RESTRUCTURE_SUPPORT 1 HAS_NEW_HC_FLOW_SUPPORT 0 HAS_NEW_SERDES_MAX_RESOURCE_COUNT_REPORTING_SUPPORT 0 HAS_NEW_VPR_SUPPORT 1 HAS_NONSOCKET_TECHNOLOGY_MIGRATION_SUPPORT 0 HAS_NO_HARDBLOCK_PARTITION_SUPPORT 0 HAS_NO_JTAG_USERCODE_SUPPORT 0 HAS_OPERATING_SETTINGS_AND_CONDITIONS_REPORTING_SUPPORT 1 HAS_PAD_LOCATION_ASSIGNMENT_SUPPORT 1 HAS_PARTIAL_RECONFIG_SUPPORT 0 HAS_PHYSICAL_NETLIST_OUTPUT 0 HAS_PHYSICAL_ROUTING_SUPPORT 0 HAS_PIN_SPECIFIC_VOLTAGE_SUPPORT 0 HAS_PLDM_REF_SUPPORT 1 HAS_POWER_ESTIMATION_SUPPORT 1 HAS_PRELIMINARY_CLOCK_UNCERTAINTY_NUMBERS 0 HAS_PRE_FITTER_FPP_SUPPORT 0 HAS_PRE_FITTER_LUTRAM_NETLIST_CHECKER_ENABLED 0 HAS_PVA_SUPPORT 1 HAS_RCF_SUPPORT 1 HAS_RCF_SUPPORT_FOR_DEBUGGING 0 HAS_RED_BLACK_SEPARATION_SUPPORT 0 HAS_RE_LEVEL_TIMING_GRAPH_SUPPORT 0 HAS_RISEFALL_DELAY_SUPPORT 1 HAS_SIGNAL_PROBE_SUPPORT 1 HAS_SIGNAL_TAP_SUPPORT 1 HAS_SIMULATOR_SUPPORT 1 HAS_SPLIT_IO_SUPPORT 0 HAS_SPLIT_LC_SUPPORT 1 HAS_SYNTH_FSYN_NETLIST_OPT_SUPPORT 0 HAS_SYNTH_NETLIST_OPT_RETIME_SUPPORT 1 HAS_SYNTH_NETLIST_OPT_SUPPORT 1 HAS_TCL_FITTER_SUPPORT 0 HAS_TECHNOLOGY_MIGRATION_SUPPORT 0 HAS_TEMPLATED_REGISTER_PACKING_SUPPORT 1 HAS_TIME_BORROWING_SUPPORT 0 HAS_TIMING_DRIVEN_SYNTHESIS_SUPPORT 1 HAS_TIMING_INFO_SUPPORT 1 HAS_TIMING_OPERATING_CONDITIONS 0 HAS_TIMING_SIMULATION_SUPPORT 1 HAS_TITAN_BASED_MAC_REGISTER_PACKER_SUPPORT 0 HAS_U2B2_SUPPORT 0 HAS_USER_HIGH_SPEED_LOW_POWER_TILE_SUPPORT 0 HAS_USE_FITTER_INFO_SUPPORT 1 HAS_VCCPD_POWER_RAIL 0 HAS_VERTICAL_MIGRATION_SUPPORT 1 HAS_VIEWDRAW_SYMBOL_SUPPORT 1 HAS_VIO_SUPPORT 1 HAS_VIRTUAL_DEVICES 0 HAS_WYSIWYG_DFFEAS_SUPPORT 0 HAS_XIBISO_WRITER_SUPPORT 0 IFP_USE_LEGACY_IO_CHECKER 0 INCREMENTAL_DESIGN_SUPPORTS_COMPATIBLE_CONSTRAINTS 0 INSTALLED 0 IS_CONFIG_ROM 0 IS_DEFAULT_FAMILY 0 IS_HARDCOPY_FAMILY 0 LVDS_IO 0 M10K_MEMORY 0 M144K_MEMORY 0 M20K_MEMORY 0 M4K_MEMORY 1 M512_MEMORY 0 M9K_MEMORY 0 MLAB_MEMORY 0 MRAM_MEMORY 0 NOT_LISTED 0 NO_RPE_SUPPORT 0 NO_SUPPORT_FOR_LOGICLOCK_CONTENT_BACK_ANNOTATION 0 NO_SUPPORT_FOR_STA_CLOCK_UNCERTAINTY_CHECK 1 NO_TDC_SUPPORT 0 POSTFIT_BAK_DATABASE_EXPORT_ENABLED 1 POSTMAP_BAK_DATABASE_EXPORT_ENABLED 1 PROGRAMMER_SUPPORT 1 QFIT_IN_DEVELOPMENT 0 QMAP_IN_DEVELOPMENT 0 RAM_LOGICAL_NAME_CHECKING_IN_CUT_ENABLED 1 REPORTS_METASTABILITY_MTBF 0 REQUIRES_INSTALLATION_PATCH 0 REQUIRES_LIST_OF_TEMPERATURE_AND_VOLTAGE_OPERATING_CONDITIONS 0 RESERVES_SIGNAL_PROBE_PINS 0 RESOLVE_MAX_FANOUT_EARLY 1 RESOLVE_MAX_FANOUT_LATE 0 RESPECTS_FIXED_SIZED_LOCKED_LOCATION_LOGICLOCK 1 RESTRICTED_USER_SELECTION 0 RISEFALL_SUPPORT_IS_HIDDEN 1 STRICT_TIMING_DB_CHECKS 0 SUPPORTS_ADDITIONAL_OPTIONS_FOR_UNUSED_IO 1 SUPPORTS_CRC 1 SUPPORTS_DIFFERENTIAL_AIOT_BOARD_TRACE_MODEL 0 SUPPORTS_DSP_BALANCING_BACK_ANNOTATION 0 SUPPORTS_GENERATION_OF_EARLY_POWER_ESTIMATOR_FILE 1 SUPPORTS_GLOBAL_SIGNAL_BACK_ANNOTATION 0 SUPPORTS_MAC_CHAIN_OUT_ADDER 0 SUPPORTS_RAM_PACKING_BACK_ANNOTATION 0 SUPPORTS_REG_PACKING_BACK_ANNOTATION 0 SUPPORTS_SIGNALPROBE_REGISTER_PIPELINING 1 SUPPORTS_SINGLE_ENDED_AIOT_BOARD_TRACE_MODEL 0 SUPPORTS_USER_MANUAL_LOGIC_DUPLICATION 1 TMV_RUN_CUSTOMIZABLE_VIEWER 1 TMV_RUN_INTERNAL_DETAILS 1 TMV_RUN_INTERNAL_DETAILS_ON_IO 1 TMV_RUN_INTERNAL_DETAILS_ON_IOBUF 0 TMV_RUN_INTERNAL_DETAILS_ON_LCELL 0 TMV_RUN_INTERNAL_DETAILS_ON_LRAM 0 TRANSCEIVER_3G_BLOCK 0 TRANSCEIVER_6G_BLOCK 0 USES_ACV_FOR_FLED 1 USES_ADB_FOR_BACK_ANNOTATION 0 USES_ALTERA_LNSIM 0 USES_ASIC_ROUTING_POWER_CALCULATOR 0 USES_DATA_DRIVEN_PLL_COMPUTATION_UTIL 1 USES_DEV 1 USES_ICP_FOR_ECO_FITTER 0 USES_LIBERTY_TIMING 0 USES_POWER_SIGNAL_ACTIVITIES 1 USES_THIRD_GENERATION_TIMING_MODELS_TIS 0 USES_U2B2_TIMING_MODELS 0 USE_ADVANCED_IO_POWER_BY_DEFAULT 0 USE_ADVANCED_IO_TIMING_BY_DEFAULT 0 USE_BASE_FAMILY_DDB_PATH 0 USE_OCT_AUTO_CALIBRATION 0 USE_RELAX_IO_ASSIGNMENT_RULES 1 USE_RISEFALL_ONLY 0 USE_SEPARATE_LIST_FOR_TECH_MIGRATION 0 USE_SINGLE_COMPILER_PASS_PLL_MIF_FILE_WRITER 0 USE_TITAN_IO_BASED_IO_REGISTER_PACKER_UTIL 0 WYSIWYG_BUS_WIDTH_CHECKING_IN_CUT_ENABLED 0
tightlyCoupledDataMaster0MapParam
tightlyCoupledDataMaster1MapParam
tightlyCoupledDataMaster2MapParam
tightlyCoupledDataMaster3MapParam
tightlyCoupledInstructionMaster0MapParam
tightlyCoupledInstructionMaster1MapParam
tightlyCoupledInstructionMaster2MapParam
tightlyCoupledInstructionMaster3MapParam
deviceFamily | UNKNOWN
generateLegacySim | false

Software Assignments

BIG_ENDIAN | 0
BREAK_ADDR | 0x01810820
CPU_FREQ | 50000000u
CPU_ID_SIZE | 1
CPU_ID_VALUE | 0x00000000
CPU_IMPLEMENTATION | "fast"
DATA_ADDR_WIDTH | 25
DCACHE_LINE_SIZE | 32
DCACHE_LINE_SIZE_LOG2 | 5
DCACHE_SIZE | 2048
EXCEPTION_ADDR | 0x0180c020
FLUSHDA_SUPPORTED
HARDWARE_DIVIDE_PRESENT | 1
HARDWARE_MULTIPLY_PRESENT | 1
HARDWARE_MULX_PRESENT | 0
HAS_DEBUG_CORE | 1
HAS_DEBUG_STUB
HAS_JMPI_INSTRUCTION
ICACHE_LINE_SIZE | 32
ICACHE_LINE_SIZE_LOG2 | 5
ICACHE_SIZE | 4096
INITDA_SUPPORTED
INST_ADDR_WIDTH | 25
NUM_OF_SHADOW_REG_SETS | 0
RESET_ADDR | 0x0180c000

## onchip_memory2_0

altera_avalon_onchip_memory2 v13.0.1.99.2

clk_0 | clk | onchip_memory2_0
| clk1
| clk_reset
| reset1
nios2_qsys_0 | instruction_master
| s1
| data_master
| s1
| jtag_debug_module_reset
| reset1

Parameters

allowInSystemMemoryContentEditor | false
blockType | AUTO
dataWidth | 32
dualPort | false
initMemContent | true
initializationFileName | onchip_mem.hex
instanceID | NONE
memorySize | 16384
readDuringWriteMode | DONT_CARE
simAllowMRAMContentsFile | false
simMemInitOnlyFilename | 0
singleClockOperation | false
slave1Latency | 1
slave2Latency | 1
useNonDefaultInitFile | false
useShallowMemBlocks | false
writable | true
autoInitializationFileName | niosII_flash_onchip_memory2_0
deviceFamily | CYCLONEII

deviceFeatures

ADDRESS_STALL 1 CELL_LEVEL_BACK_ANNOTATION_DISABLED 0 COMPILER_SUPPORT 1 DSP 0 DSP_SHIFTER_BLOCK 0 DUMP_ASM_LAB_BITS_FOR_POWER 1 EMUL 1 ENABLE_ADVANCED_IO_ANALYSIS_GUI_FEATURES 0 EPCS 1 ESB 0 FAKE1 0 FAKE2 0 FAKE3 0 FAMILY_LEVEL_INSTALLATION_ONLY 1 FITTER_USE_FALLING_EDGE_DELAY 0 GENERATE_DC_ON_CURRENT_WARNING_FOR_INTERNAL_CLAMPING_DIODE 0 HARDCOPY 0 HAS_18_BIT_MULTS 0 HAS_ACE_SUPPORT 1 HAS_ADJUSTABLE_OUTPUT_IO_TIMING_MEAS_POINT 0 HAS_ADVANCED_IO_INVERTED_CORNER 0 HAS_ADVANCED_IO_POWER_SUPPORT 0 HAS_ADVANCED_IO_TIMING_SUPPORT 0 HAS_ALM_SUPPORT 0 HAS_ATOM_AND_ROUTING_POWER_MODELED_TOGETHER 0 HAS_AUTO_DERIVE_CLOCK_UNCERTAINTY_SUPPORT 0 HAS_AUTO_FIT_SUPPORT 1 HAS_BALANCED_OPT_TECHNIQUE_SUPPORT 1 HAS_BENEFICIAL_SKEW_SUPPORT 0 HAS_BITLEVEL_DRIVE_STRENGTH_CONTROL 0 HAS_BSDL_FILE_GENERATION 0 HAS_CGA_SUPPORT 1 HAS_CHECK_NETLIST_SUPPORT 1 HAS_CLOCK_REGION_CHECKER_ENABLED 1 HAS_CORE_JUNCTION_TEMP_DERATING 1 HAS_CROSSTALK_SUPPORT 0 HAS_CUSTOM_REGION_SUPPORT 1 HAS_DAP_JTAG_FROM_HPS 0 HAS_DATA_DRIVEN_ACVQ_HSSI_SUPPORT 0 HAS_DDB_FDI_SUPPORT 0 HAS_DESIGN_ANALYZER_SUPPORT 1 HAS_DETAILED_IO_RAIL_POWER_MODEL 1 HAS_DETAILED_LEIM_STATIC_POWER_MODEL 0 HAS_DETAILED_LE_POWER_MODEL 1 HAS_DETAILED_ROUTING_MUX_STATIC_POWER_MODEL 0 HAS_DETAILED_THERMAL_CIRCUIT_PARAMETER_SUPPORT 1 HAS_DEVICE_MIGRATION_SUPPORT 1 HAS_DIAGONAL_MIGRATION_SUPPORT 0 HAS_EMIF_TOOLKIT_SUPPORT 0 HAS_ERROR_DETECTION_SUPPORT 0 HAS_FAMILY_VARIANT_MIGRATION_SUPPORT 0 HAS_FANOUT_FREE_NODE_SUPPORT 1 HAS_FAST_FIT_SUPPORT 1 HAS_FITTER_EARLY_TIMING_ESTIMATE_SUPPORT 1 HAS_FITTER_ECO_SUPPORT 1 HAS_FIT_NETLIST_OPT_RETIME_SUPPORT 1 HAS_FIT_NETLIST_OPT_SUPPORT 1 HAS_FORMAL_VERIFICATION_SUPPORT 1 HAS_FPGA_XCHANGE_SUPPORT 1 HAS_FSAC_LUTRAM_REGISTER_PACKING_SUPPORT 0 HAS_FULL_DAT_MIN_TIMING_SUPPORT 1 HAS_FULL_INCREMENTAL_DESIGN_SUPPORT 1 HAS_FUNCTIONAL_SIMULATION_SUPPORT 1 HAS_FUNCTIONAL_VERILOG_SIMULATION_SUPPORT 0 HAS_FUNCTIONAL_VHDL_SIMULATION_SUPPORT 0 HAS_GLITCH_FILTERING_SUPPORT 1 HAS_HC_READY_SUPPORT 0 HAS_HIGH_SPEED_LOW_POWER_TILE_SUPPORT 0 HAS_HOLD_TIME_AVOIDANCE_ACROSS_CLOCK_SPINE_SUPPORT 1 HAS_HSPICE_WRITER_SUPPORT 0 HAS_HSSI_POWER_CALCULATOR 0 HAS_IBISO_WRITER_SUPPORT 1 HAS_INCREMENTAL_DAT_SUPPORT 0 HAS_INCREMENTAL_SYNTHESIS_SUPPORT 1 HAS_INTERFACE_PLANNER_SUPPORT 0 HAS_IO_ASSIGNMENT_ANALYSIS_SUPPORT 1 HAS_IO_DECODER 0 HAS_IO_PLACEMENT_OPTIMIZATION_SUPPORT 1 HAS_IO_SMART_RECOMPILE_SUPPORT 1 HAS_JITTER_SUPPORT 0 HAS_JTAG_SLD_HUB_SUPPORT 1 HAS_LIMITED_TCL_FITTER_SUPPORT 0 HAS_LOGIC_LOCK_SUPPORT 1 HAS_MICROPROCESSOR 0 HAS_MIF_SMART_COMPILE_SUPPORT 1 HAS_MINMAX_TIMING_MODELING_SUPPORT 0 HAS_MIN_TIMING_ANALYSIS_SUPPORT 1 HAS_MUX_RESTRUCTURE_SUPPORT 1 HAS_NEW_HC_FLOW_SUPPORT 0 HAS_NEW_SERDES_MAX_RESOURCE_COUNT_REPORTING_SUPPORT 0 HAS_NEW_VPR_SUPPORT 1 HAS_NONSOCKET_TECHNOLOGY_MIGRATION_SUPPORT 0 HAS_NO_HARDBLOCK_PARTITION_SUPPORT 0 HAS_NO_JTAG_USERCODE_SUPPORT 0 HAS_OPERATING_SETTINGS_AND_CONDITIONS_REPORTING_SUPPORT 1 HAS_PAD_LOCATION_ASSIGNMENT_SUPPORT 1 HAS_PARTIAL_RECONFIG_SUPPORT 0 HAS_PHYSICAL_NETLIST_OUTPUT 0 HAS_PHYSICAL_ROUTING_SUPPORT 0 HAS_PIN_SPECIFIC_VOLTAGE_SUPPORT 0 HAS_PLDM_REF_SUPPORT 1 HAS_POWER_ESTIMATION_SUPPORT 1 HAS_PRELIMINARY_CLOCK_UNCERTAINTY_NUMBERS 0 HAS_PRE_FITTER_FPP_SUPPORT 0 HAS_PRE_FITTER_LUTRAM_NETLIST_CHECKER_ENABLED 0 HAS_PVA_SUPPORT 1 HAS_RCF_SUPPORT 1 HAS_RCF_SUPPORT_FOR_DEBUGGING 0 HAS_RED_BLACK_SEPARATION_SUPPORT 0 HAS_RE_LEVEL_TIMING_GRAPH_SUPPORT 0 HAS_RISEFALL_DELAY_SUPPORT 1 HAS_SIGNAL_PROBE_SUPPORT 1 HAS_SIGNAL_TAP_SUPPORT 1 HAS_SIMULATOR_SUPPORT 1 HAS_SPLIT_IO_SUPPORT 0 HAS_SPLIT_LC_SUPPORT 1 HAS_SYNTH_FSYN_NETLIST_OPT_SUPPORT 0 HAS_SYNTH_NETLIST_OPT_RETIME_SUPPORT 1 HAS_SYNTH_NETLIST_OPT_SUPPORT 1 HAS_TCL_FITTER_SUPPORT 0 HAS_TECHNOLOGY_MIGRATION_SUPPORT 0 HAS_TEMPLATED_REGISTER_PACKING_SUPPORT 1 HAS_TIME_BORROWING_SUPPORT 0 HAS_TIMING_DRIVEN_SYNTHESIS_SUPPORT 1 HAS_TIMING_INFO_SUPPORT 1 HAS_TIMING_OPERATING_CONDITIONS 0 HAS_TIMING_SIMULATION_SUPPORT 1 HAS_TITAN_BASED_MAC_REGISTER_PACKER_SUPPORT 0 HAS_U2B2_SUPPORT 0 HAS_USER_HIGH_SPEED_LOW_POWER_TILE_SUPPORT 0 HAS_USE_FITTER_INFO_SUPPORT 1 HAS_VCCPD_POWER_RAIL 0 HAS_VERTICAL_MIGRATION_SUPPORT 1 HAS_VIEWDRAW_SYMBOL_SUPPORT 1 HAS_VIO_SUPPORT 1 HAS_VIRTUAL_DEVICES 0 HAS_WYSIWYG_DFFEAS_SUPPORT 0 HAS_XIBISO_WRITER_SUPPORT 0 IFP_USE_LEGACY_IO_CHECKER 0 INCREMENTAL_DESIGN_SUPPORTS_COMPATIBLE_CONSTRAINTS 0 INSTALLED 0 IS_CONFIG_ROM 0 IS_DEFAULT_FAMILY 0 IS_HARDCOPY_FAMILY 0 LVDS_IO 0 M10K_MEMORY 0 M144K_MEMORY 0 M20K_MEMORY 0 M4K_MEMORY 1 M512_MEMORY 0 M9K_MEMORY 0 MLAB_MEMORY 0 MRAM_MEMORY 0 NOT_LISTED 0 NO_RPE_SUPPORT 0 NO_SUPPORT_FOR_LOGICLOCK_CONTENT_BACK_ANNOTATION 0 NO_SUPPORT_FOR_STA_CLOCK_UNCERTAINTY_CHECK 1 NO_TDC_SUPPORT 0 POSTFIT_BAK_DATABASE_EXPORT_ENABLED 1 POSTMAP_BAK_DATABASE_EXPORT_ENABLED 1 PROGRAMMER_SUPPORT 1 QFIT_IN_DEVELOPMENT 0 QMAP_IN_DEVELOPMENT 0 RAM_LOGICAL_NAME_CHECKING_IN_CUT_ENABLED 1 REPORTS_METASTABILITY_MTBF 0 REQUIRES_INSTALLATION_PATCH 0 REQUIRES_LIST_OF_TEMPERATURE_AND_VOLTAGE_OPERATING_CONDITIONS 0 RESERVES_SIGNAL_PROBE_PINS 0 RESOLVE_MAX_FANOUT_EARLY 1 RESOLVE_MAX_FANOUT_LATE 0 RESPECTS_FIXED_SIZED_LOCKED_LOCATION_LOGICLOCK 1 RESTRICTED_USER_SELECTION 0 RISEFALL_SUPPORT_IS_HIDDEN 1 STRICT_TIMING_DB_CHECKS 0 SUPPORTS_ADDITIONAL_OPTIONS_FOR_UNUSED_IO 1 SUPPORTS_CRC 1 SUPPORTS_DIFFERENTIAL_AIOT_BOARD_TRACE_MODEL 0 SUPPORTS_DSP_BALANCING_BACK_ANNOTATION 0 SUPPORTS_GENERATION_OF_EARLY_POWER_ESTIMATOR_FILE 1 SUPPORTS_GLOBAL_SIGNAL_BACK_ANNOTATION 0 SUPPORTS_MAC_CHAIN_OUT_ADDER 0 SUPPORTS_RAM_PACKING_BACK_ANNOTATION 0 SUPPORTS_REG_PACKING_BACK_ANNOTATION 0 SUPPORTS_SIGNALPROBE_REGISTER_PIPELINING 1 SUPPORTS_SINGLE_ENDED_AIOT_BOARD_TRACE_MODEL 0 SUPPORTS_USER_MANUAL_LOGIC_DUPLICATION 1 TMV_RUN_CUSTOMIZABLE_VIEWER 1 TMV_RUN_INTERNAL_DETAILS 1 TMV_RUN_INTERNAL_DETAILS_ON_IO 1 TMV_RUN_INTERNAL_DETAILS_ON_IOBUF 0 TMV_RUN_INTERNAL_DETAILS_ON_LCELL 0 TMV_RUN_INTERNAL_DETAILS_ON_LRAM 0 TRANSCEIVER_3G_BLOCK 0 TRANSCEIVER_6G_BLOCK 0 USES_ACV_FOR_FLED 1 USES_ADB_FOR_BACK_ANNOTATION 0 USES_ALTERA_LNSIM 0 USES_ASIC_ROUTING_POWER_CALCULATOR 0 USES_DATA_DRIVEN_PLL_COMPUTATION_UTIL 1 USES_DEV 1 USES_ICP_FOR_ECO_FITTER 0 USES_LIBERTY_TIMING 0 USES_POWER_SIGNAL_ACTIVITIES 1 USES_THIRD_GENERATION_TIMING_MODELS_TIS 0 USES_U2B2_TIMING_MODELS 0 USE_ADVANCED_IO_POWER_BY_DEFAULT 0 USE_ADVANCED_IO_TIMING_BY_DEFAULT 0 USE_BASE_FAMILY_DDB_PATH 0 USE_OCT_AUTO_CALIBRATION 0 USE_RELAX_IO_ASSIGNMENT_RULES 1 USE_RISEFALL_ONLY 0 USE_SEPARATE_LIST_FOR_TECH_MIGRATION 0 USE_SINGLE_COMPILER_PASS_PLL_MIF_FILE_WRITER 0 USE_TITAN_IO_BASED_IO_REGISTER_PACKER_UTIL 0 WYSIWYG_BUS_WIDTH_CHECKING_IN_CUT_ENABLED 0
derived_set_addr_width | 12
derived_gui_ram_block_type | Automatic
derived_is_hardcopy | false
derived_init_file_name | niosII_flash_onchip_memory2_0.hex
generateLegacySim | false

Software Assignments

ALLOW_IN_SYSTEM_MEMORY_CONTENT_EDITOR | 0
ALLOW_MRAM_SIM_CONTENTS_ONLY_FILE | 0
CONTENTS_INFO | ""
DUAL_PORT | 0
GUI_RAM_BLOCK_TYPE | AUTO
INIT_CONTENTS_FILE | niosII_flash_onchip_memory2_0
INIT_MEM_CONTENT | 1
INSTANCE_ID | NONE
NON_DEFAULT_INIT_FILE_ENABLED | 0
RAM_BLOCK_TYPE | AUTO
READ_DURING_WRITE_MODE | DONT_CARE
SINGLE_CLOCK_OP | 0
SIZE_MULTIPLE | 1
SIZE_VALUE | 16384
WRITABLE | 1

## jtag_uart_0

altera_avalon_jtag_uart v13.0.1.99.2

clk_0 | clk | jtag_uart_0
| clk
| clk_reset
| reset
nios2_qsys_0 | data_master
| avalon_jtag_slave
| d_irq
| irq
| jtag_debug_module_reset
| reset
| instruction_master
| avalon_jtag_slave

Parameters

allowMultipleConnections | false
hubInstanceID | 0
readBufferDepth | 64
readIRQThreshold | 8
simInputCharacterStream
simInteractiveOptions | NO_INTERACTIVE_WINDOWS
useRegistersForReadBuffer | false
useRegistersForWriteBuffer | false
useRelativePathForSimFile | false
writeBufferDepth | 64
writeIRQThreshold | 8
avalonSpec | 2.0
legacySignalAllow | false
enableInteractiveInput | false
enableInteractiveOutput | false
deviceFamily | UNKNOWN
generateLegacySim | false

Software Assignments

READ_DEPTH | 64
READ_THRESHOLD | 8
WRITE_DEPTH | 64
WRITE_THRESHOLD | 8

## pio_0

altera_avalon_pio v13.0.1.99.2

clk_0 | clk | pio_0
| clk
| clk_reset
| reset
nios2_qsys_0 | data_master
| s1
| jtag_debug_module_reset
| reset
| instruction_master
| s1

Parameters

bitClearingEdgeCapReg | false
bitModifyingOutReg | false
captureEdge | false
direction | Input
edgeType | RISING
generateIRQ | false
irqType | LEVEL
resetValue | 0
simDoTestBenchWiring | false
simDrivenValue | 0
width | 4
clockRate | 50000000
derived_has_tri | false
derived_has_out | false
derived_has_in | true
derived_do_test_bench_wiring | false
derived_capture | false
derived_edge_type | NONE
derived_irq_type | NONE
derived_has_irq | false
deviceFamily | UNKNOWN
generateLegacySim | false

Software Assignments

BIT_CLEARING_EDGE_REGISTER | 0
BIT_MODIFYING_OUTPUT_REGISTER | 0
CAPTURE | 0
DATA_WIDTH | 4
DO_TEST_BENCH_WIRING | 0
DRIVEN_SIM_VALUE | 0
EDGE_TYPE | NONE
FREQ | 50000000
HAS_IN | 1
HAS_OUT | 0
HAS_TRI | 0
IRQ_TYPE | NONE
RESET_VALUE | 0

## led_matrix_avalon_0

led_matrix_avalon v1.0

clk_0 | clk | led_matrix_avalon_0
| clock
| clk_reset
| reset_n
nios2_qsys_0 | data_master
| avalon_slave
| jtag_debug_module_reset
| reset_n
| instruction_master
| avalon_slave

Parameters

WIDTH_PIXELS | 128
HEIGHT_PIXELS | 64
AUTO_CLOCK_CLOCK_RATE | 50000000
deviceFamily | UNKNOWN
generateLegacySim | false

Software Assignments
(none)

## sysid_qsys_0

altera_avalon_sysid_qsys v13.0

clk_0 | clk | sysid_qsys_0
| clk
| clk_reset
| reset
nios2_qsys_0 | data_master
| control_slave
| instruction_master
| control_slave
| jtag_debug_module_reset
| reset

Parameters

id | 0
timestamp | 1774664414
AUTO_CLK_CLOCK_RATE | 50000000
AUTO_DEVICE_FAMILY | CYCLONEII
deviceFamily | Cyclone II
generateLegacySim | false

Software Assignments

ID | 0
TIMESTAMP | 1774664414

## ps2_interface_0

ps2_interface v1.0

clk_0 | clk | ps2_interface_0
| clock
| clk_reset
| reset
nios2_qsys_0 | data_master
| avalon_slave_0
| jtag_debug_module_reset
| reset
| instruction_master
| avalon_slave_0

Parameters

AUTO_CLOCK_CLOCK_RATE | 50000000
deviceFamily | UNKNOWN
generateLegacySim | false

Software Assignments
(none)

## new_sdram_controller_0

altera_avalon_new_sdram_controller v13.0.1.99.2

clk_0 | clk | new_sdram_controller_0
| clk
| clk_reset
| reset
nios2_qsys_0 | instruction_master
| s1
| data_master
| s1
| jtag_debug_module_reset
| reset

Parameters

TAC | 5.5
TRCD | 20.0
TRFC | 70.0
TRP | 20.0
TWR | 14.0
casLatency | 3
columnWidth | 8
dataWidth | 16
generateSimulationModel | false
initRefreshCommands | 2
model | single_Micron_MT48LC4M32B2_7_chip
numberOfBanks | 4
numberOfChipSelects | 1
pinsSharedViaTriState | false
powerUpDelay | 100.0
refreshPeriod | 7.8125
rowWidth | 12
masteredTristateBridgeSlave | 0
TMRD | 3
initNOPDelay | 0.0
registerDataIn | true
clockRate | 50000000
componentName | niosII_flash_new_sdram_controller_0
size | 8388608
addressWidth | 22
bankWidth | 2
deviceFamily | UNKNOWN
generateLegacySim | false

Software Assignments

CAS_LATENCY | 3
CONTENTS_INFO
INIT_NOP_DELAY | 0.0
INIT_REFRESH_COMMANDS | 2
IS_INITIALIZED | 1
POWERUP_DELAY | 100.0
REFRESH_PERIOD | 7.8125
REGISTER_DATA_IN | 1
SDRAM_ADDR_WIDTH | 22
SDRAM_BANK_WIDTH | 2
SDRAM_COL_WIDTH | 8
SDRAM_DATA_WIDTH | 16
SDRAM_NUM_BANKS | 4
SDRAM_NUM_CHIPSELECTS | 1
SDRAM_ROW_WIDTH | 12
SHARED_DATA | 0
SIM_MODEL_BASE | 0
STARVATION_INDICATOR | 0
TRISTATE_BRIDGE_SLAVE | ""
T_AC | 5.5
T_MRD | 3
T_RCD | 20.0
T_RFC | 70.0
T_RP | 20.0
T_WR | 14.0

## audio

AUDIO_IF v2.0

clk_0 | clk_reset | audio
| clock_sink_reset
nios2_qsys_0 | data_master
| avalon_slave
| instruction_master
| avalon_slave
| jtag_debug_module_reset
| clock_sink_reset
clk_audio | clk
| clock_sink
| clk_reset
| clock_sink_reset

Parameters

AUTO_CLOCK_SINK_CLOCK_RATE | 1843200
deviceFamily | UNKNOWN
generateLegacySim | false

Software Assignments
(none)

## i2c_clk

altera_avalon_pio v13.0.1.99.2

clk_0 | clk | i2c_clk
| clk
| clk_reset
| reset
nios2_qsys_0 | data_master
| s1
| instruction_master
| s1
| jtag_debug_module_reset
| reset

Parameters

bitClearingEdgeCapReg | false
bitModifyingOutReg | false
captureEdge | false
direction | Output
edgeType | RISING
generateIRQ | false
irqType | LEVEL
resetValue | 0
simDoTestBenchWiring | false
simDrivenValue | 0
width | 1
clockRate | 50000000
derived_has_tri | false
derived_has_out | true
derived_has_in | false
derived_do_test_bench_wiring | false
derived_capture | false
derived_edge_type | NONE
derived_irq_type | NONE
derived_has_irq | false
deviceFamily | UNKNOWN
generateLegacySim | false

Software Assignments

BIT_CLEARING_EDGE_REGISTER | 0
BIT_MODIFYING_OUTPUT_REGISTER | 0
CAPTURE | 0
DATA_WIDTH | 1
DO_TEST_BENCH_WIRING | 0
DRIVEN_SIM_VALUE | 0
EDGE_TYPE | NONE
FREQ | 50000000
HAS_IN | 0
HAS_OUT | 1
HAS_TRI | 0
IRQ_TYPE | NONE
RESET_VALUE | 0

## i2c_sda

altera_avalon_pio v13.0.1.99.2

clk_0 | clk | i2c_sda
| clk
| clk_reset
| reset
nios2_qsys_0 | jtag_debug_module_reset
| reset
| instruction_master
| s1
| data_master
| s1

Parameters

bitClearingEdgeCapReg | false
bitModifyingOutReg | false
captureEdge | false
direction | Bidir
edgeType | RISING
generateIRQ | false
irqType | LEVEL
resetValue | 0
simDoTestBenchWiring | false
simDrivenValue | 0
width | 1
clockRate | 50000000
derived_has_tri | true
derived_has_out | false
derived_has_in | false
derived_do_test_bench_wiring | false
derived_capture | false
derived_edge_type | NONE
derived_irq_type | NONE
derived_has_irq | false
deviceFamily | UNKNOWN
generateLegacySim | false

Software Assignments

BIT_CLEARING_EDGE_REGISTER | 0
BIT_MODIFYING_OUTPUT_REGISTER | 0
CAPTURE | 0
DATA_WIDTH | 1
DO_TEST_BENCH_WIRING | 0
DRIVEN_SIM_VALUE | 0
EDGE_TYPE | NONE
FREQ | 50000000
HAS_IN | 0
HAS_OUT | 0
HAS_TRI | 1
IRQ_TYPE | NONE
RESET_VALUE | 0

## clk_audio

clock_source v13.0

clk_0 | clk_reset | clk_audio
| clk_in_reset
nios2_qsys_0 | jtag_debug_module_reset
| clk_in_reset
| | | clk | audio
| | | clock_sink
| | | clk_reset
| | | clock_sink_reset

Parameters

clockFrequency | 1843200
clockFrequencyKnown | true
inputClockFrequency | 0
resetSynchronousEdges | NONE
deviceFamily | UNKNOWN
generateLegacySim | false

Software Assignments
(none)

## timer_0

altera_avalon_timer v13.0.1.99.2

clk_0 | clk | timer_0
| clk
| clk_reset
| reset
nios2_qsys_0 | jtag_debug_module_reset
| reset
| instruction_master
| s1
| data_master
| s1
| d_irq
| irq

Parameters

alwaysRun | false
counterSize | 32
fixedPeriod | false
period | 1
periodUnits | MSEC
resetOutput | false
snapshot | true
timeoutPulseOutput | false
systemFrequency | 50000000
timerPreset | FULL_FEATURED
periodUnitsString | ms
valueInSecond | 0
loadValue | 49999
mult | 0
ticksPerSec | 1000
slave_address_width | 3
deviceFamily | UNKNOWN
generateLegacySim | false

Software Assignments

ALWAYS_RUN | 0
COUNTER_SIZE | 32
FIXED_PERIOD | 0
FREQ | 50000000
LOAD_VALUE | 49999
MULT | 0.001
PERIOD | 1
PERIOD_UNITS | ms
RESET_OUTPUT | 0
SNAPSHOT | 1
TICKS_PER_SEC | 1000.0
TIMEOUT_PULSE_OUTPUT | 0

## generic_tristate_controller_0

altera_generic_tristate_controller v13.0

clk_0 | clk_reset | generic_tristate_controller_0
| reset
| clk
| clk
nios2_qsys_0 | jtag_debug_module_reset
| reset
| instruction_master
| uas
| data_master
| uas

Parameters

TCM_ADDRESS_W | 22
TCM_DATA_W | 8
TCM_BYTEENABLE_W | 1
TCM_READ_WAIT | 160
TCM_WRITE_WAIT | 9
TCM_SETUP_WAIT | 3
TCM_DATA_HOLD | 0
TCM_MAX_PENDING_READ_TRANSACTIONS | 3
TCM_TURNAROUND_TIME | 2
TCM_TIMING_UNITS | 0
TCM_READLATENCY | 2
TCM_SYMBOLS_PER_WORD | 1
USE_READDATA | 1
USE_WRITEDATA | 1
USE_READ | 1
USE_WRITE | 1
USE_BEGINTRANSFER | 0
USE_BYTEENABLE | 0
USE_CHIPSELECT | 1
USE_LOCK | 0
USE_ADDRESS | 1
USE_WAITREQUEST | 0
USE_WRITEBYTEENABLE | 0
USE_OUTPUTENABLE | 0
USE_RESETREQUEST | 0
USE_IRQ | 0
USE_RESET_OUTPUT | 0
ACTIVE_LOW_READ | 1
ACTIVE_LOW_LOCK | 0
ACTIVE_LOW_WRITE | 1
ACTIVE_LOW_CHIPSELECT | 1
ACTIVE_LOW_BYTEENABLE | 0
ACTIVE_LOW_OUTPUTENABLE | 0
ACTIVE_LOW_WRITEBYTEENABLE | 0
ACTIVE_LOW_WAITREQUEST | 0
ACTIVE_LOW_BEGINTRANSFER | 0
ACTIVE_LOW_RESETREQUEST | 0
ACTIVE_LOW_IRQ | 0
ACTIVE_LOW_RESET_OUTPUT | 0
CHIPSELECT_THROUGH_READLATENCY | 0
IS_MEMORY_DEVICE | 1
MODULE_ASSIGNMENT_KEYS | embeddedsw.configuration.hwClassnameDriverSupportList,embeddedsw.configuration.hwClassnameDriverSupportDefault,embeddedsw.CMacro.SETUP_VALUE,embeddedsw.CMacro.WAIT_VALUE,embeddedsw.CMacro.HOLD_VALUE,embeddedsw.CMacro.TIMING_UNITS,embeddedsw.CMacro.SIZE,embeddedsw.memoryInfo.MEM_INIT_DATA_WIDTH,embeddedsw.memoryInfo.HAS_BYTE_LANE,embeddedsw.memoryInfo.IS_FLASH,embeddedsw.memoryInfo.GENERATE_DAT_SYM,embeddedsw.memoryInfo.GENERATE_FLASH,embeddedsw.memoryInfo.DAT_SYM_INSTALL_DIR,embeddedsw.memoryInfo.FLASH_INSTALL_DIR
MODULE_ASSIGNMENT_VALUES | altera_avalon_lan91c111:altera_avalon_cfi_flash,altera_avalon_cfi_flash,0,0,0,ns,262144u,8,0,1,1,1,SIM_DIR,APP_DIR
INTERFACE_ASSIGNMENT_KEYS | embeddedsw.configuration.isFlash,embeddedsw.configuration.isMemoryDevice,embeddedsw.configuration.isNonVolatileStorage
INTERFACE_ASSIGNMENT_VALUES | 1,1,1
CLOCK_RATE | 50000000
AUTO_CLK_CLOCK_DOMAIN | 1
AUTO_CLK_RESET_DOMAIN | 1
AUTO_TRISTATECONDUIT_MASTERS
AUTO_DEVICE_FAMILY | CYCLONEII
AUTO_DEVICE | EP2C35F672C6
deviceFamily | Cyclone II
generateLegacySim | false

Software Assignments

HOLD_VALUE | 0
SETUP_VALUE | 0
SIZE | 262144u
TIMING_UNITS | ns
WAIT_VALUE | 0

generation took 0,00 seconds | rendering took 0,09 seconds

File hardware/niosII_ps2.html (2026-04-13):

NiosII_ps2

2026.04.13.16:54:17 | Datasheet

Overview

clk_0 | NiosII_ps2

Processor
nios2_qsys_0 Nios II 13.0
All Components
nios2_qsys_0 altera_nios2_qsys 13.0
onchip_memory2_0 altera_avalon_onchip_memory2 13.0.1.99.2
jtag_uart_0 altera_avalon_jtag_uart 13.0.1.99.2
pio_0 altera_avalon_pio 13.0.1.99.2
led_matrix_avalon_0 led_matrix_avalon 1.0
sysid_qsys_0 altera_avalon_sysid_qsys 13.0
ps2_interface_0 ps2_interface 1.0
new_sdram_controller_0 altera_avalon_new_sdram_controller 13.0.1.99.2
i2c_clk altera_avalon_pio 13.0.1.99.2
i2c_sda altera_avalon_pio 13.0.1.99.2
uart_0 altera_avalon_uart 13.0.1.99.2
sd_spi_0 altera_avalon_spi 13.0.1.99.2
generic_tristate_controller_0 altera_generic_tristate_controller 13.0

Memory Map

| nios2_qsys_0
| data_master | instruction_master
nios2_qsys_0
jtag_debug_module | 0x01810800 | 0x01810800
onchip_memory2_0
s1 | 0x0180c000 | 0x0180c000
jtag_uart_0
avalon_jtag_slave | 0x018110b8 | 0x018110b8
pio_0
s1 | 0x01811090 | 0x01811090
led_matrix_avalon_0
avalon_slave | 0x01808000 | 0x01808000
sysid_qsys_0
control_slave | 0x018110b0 | 0x018110b0
ps2_interface_0
avalon_slave_0 | 0x018110c4 | 0x018110c4
new_sdram_controller_0
s1 | 0x00800000 | 0x00800000
i2c_clk
s1 | 0x01811080 | 0x01811080
i2c_sda
s1 | 0x01811070 | 0x01811070
uart_0
s1 | 0x01811020
sd_spi_0
spi_control_port | 0x01811000
generic_tristate_controller_0
uas | 0x01400000 | 0x01400000

## clk_0

clock_source v13.0

Parameters

clockFrequency | 50000000
clockFrequencyKnown | true
inputClockFrequency | 0
resetSynchronousEdges | NONE
deviceFamily | UNKNOWN
generateLegacySim | false

Software Assignments
(none)

## nios2_qsys_0

altera_nios2_qsys v13.0

clk_0 | clk | nios2_qsys_0
| clk
| clk_reset
| reset_n
| | | instruction_master | onchip_memory2_0
| | | s1
| | | data_master
| | | s1
| | | jtag_debug_module_reset
| | | reset1
| | | data_master | jtag_uart_0
| | | avalon_jtag_slave
| | | d_irq
| | | irq
| | | jtag_debug_module_reset
| | | reset
| | | instruction_master
| | | avalon_jtag_slave
| | | data_master | pio_0
| | | s1
| | | jtag_debug_module_reset
| | | reset
| | | instruction_master
| | | s1
| | | data_master | led_matrix_avalon_0
| | | avalon_slave
| | | jtag_debug_module_reset
| | | reset_n
| | | instruction_master
| | | avalon_slave
| | | data_master | sysid_qsys_0
| | | control_slave
| | | instruction_master
| | | control_slave
| | | jtag_debug_module_reset
| | | reset
| | | data_master | ps2_interface_0
| | | avalon_slave_0
| | | jtag_debug_module_reset
| | | reset
| | | instruction_master
| | | avalon_slave_0
| | | instruction_master | new_sdram_controller_0
| | | s1
| | | data_master
| | | s1
| | | jtag_debug_module_reset
| | | reset
| | | data_master | i2c_clk
| | | s1
| | | instruction_master
| | | s1
| | | jtag_debug_module_reset
| | reset
| | jtag_debug_module_reset | i2c_sda
| | reset
| | instruction_master
| | s1
| | data_master
| | s1
| | jtag_debug_module_reset | uart_0
| | reset
| | data_master
| | s1
| | d_irq
| | irq
| | jtag_debug_module_reset | sd_spi_0
| | reset
| | d_irq
| | irq
| | data_master
| | spi_control_port
| | jtag_debug_module_reset | generic_tristate_controller_0
| | reset
| | data_master
| | uas
| | instruction_master
| | uas

Parameters

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

instSlaveMapParam

<address-map><slave name='new_sdram_controller_0.s1' start='0x800000' end='0x1000000' /><slave name='generic_tristate_controller_0.uas' start='0x1400000' end='0x1800000' /><slave name='led_matrix_avalon_0.avalon_slave' start='0x1808000' end='0x180C000' /><slave name='onchip_memory2_0.s1' start='0x180C000' end='0x1810000' /><slave name='nios2_qsys_0.jtag_debug_module' start='0x1810800' end='0x1811000' /><slave name='i2c_sda.s1' start='0x1811070' end='0x1811080' /><slave name='i2c_clk.s1' start='0x1811080' end='0x1811090' /><slave name='pio_0.s1' start='0x1811090' end='0x18110A0' /><slave name='sysid_qsys_0.control_slave' start='0x18110B0' end='0x18110B8' /><slave name='jtag_uart_0.avalon_jtag_slave' start='0x18110B8' end='0x18110C0' /><slave name='ps2_interface_0.avalon_slave_0' start='0x18110C4' end='0x18110C8' /></address-map>

dataSlaveMapParam

<address-map><slave name='new_sdram_controller_0.s1' start='0x800000' end='0x1000000' /><slave name='generic_tristate_controller_0.uas' start='0x1400000' end='0x1800000' /><slave name='led_matrix_avalon_0.avalon_slave' start='0x1808000' end='0x180C000' /><slave name='onchip_memory2_0.s1' start='0x180C000' end='0x1810000' /><slave name='nios2_qsys_0.jtag_debug_module' start='0x1810800' end='0x1811000' /><slave name='sd_spi_0.spi_control_port' start='0x1811000' end='0x1811020' /><slave name='uart_0.s1' start='0x1811020' end='0x1811040' /><slave name='i2c_sda.s1' start='0x1811070' end='0x1811080' /><slave name='i2c_clk.s1' start='0x1811080' end='0x1811090' /><slave name='pio_0.s1' start='0x1811090' end='0x18110A0' /><slave name='sysid_qsys_0.control_slave' start='0x18110B0' end='0x18110B8' /><slave name='jtag_uart_0.avalon_jtag_slave' start='0x18110B8' end='0x18110C0' /><slave name='ps2_interface_0.avalon_slave_0' start='0x18110C4' end='0x18110C8' /></address-map>
clockFrequency | 50000000
deviceFamilyName | CYCLONEIII
internalIrqMaskSystemInfo | 7
customInstSlavesSystemInfo | <info/>

deviceFeaturesSystemInfo

ADDRESS_STALL 1 CELL_LEVEL_BACK_ANNOTATION_DISABLED 0 COMPILER_SUPPORT 1 DSP 0 DSP_SHIFTER_BLOCK 0 DUMP_ASM_LAB_BITS_FOR_POWER 1 EMUL 1 ENABLE_ADVANCED_IO_ANALYSIS_GUI_FEATURES 1 EPCS 1 ESB 0 FAKE1 0 FAKE2 0 FAKE3 0 FAMILY_LEVEL_INSTALLATION_ONLY 1 FITTER_USE_FALLING_EDGE_DELAY 1 GENERATE_DC_ON_CURRENT_WARNING_FOR_INTERNAL_CLAMPING_DIODE 0 HARDCOPY 0 HAS_18_BIT_MULTS 0 HAS_ACE_SUPPORT 1 HAS_ADJUSTABLE_OUTPUT_IO_TIMING_MEAS_POINT 1 HAS_ADVANCED_IO_INVERTED_CORNER 0 HAS_ADVANCED_IO_POWER_SUPPORT 1 HAS_ADVANCED_IO_TIMING_SUPPORT 1 HAS_ALM_SUPPORT 0 HAS_ATOM_AND_ROUTING_POWER_MODELED_TOGETHER 0 HAS_AUTO_DERIVE_CLOCK_UNCERTAINTY_SUPPORT 0 HAS_AUTO_FIT_SUPPORT 1 HAS_BALANCED_OPT_TECHNIQUE_SUPPORT 1 HAS_BENEFICIAL_SKEW_SUPPORT 1 HAS_BITLEVEL_DRIVE_STRENGTH_CONTROL 1 HAS_BSDL_FILE_GENERATION 0 HAS_CGA_SUPPORT 1 HAS_CHECK_NETLIST_SUPPORT 0 HAS_CLOCK_REGION_CHECKER_ENABLED 1 HAS_CORE_JUNCTION_TEMP_DERATING 0 HAS_CROSSTALK_SUPPORT 0 HAS_CUSTOM_REGION_SUPPORT 1 HAS_DAP_JTAG_FROM_HPS 0 HAS_DATA_DRIVEN_ACVQ_HSSI_SUPPORT 0 HAS_DDB_FDI_SUPPORT 0 HAS_DESIGN_ANALYZER_SUPPORT 1 HAS_DETAILED_IO_RAIL_POWER_MODEL 1 HAS_DETAILED_LEIM_STATIC_POWER_MODEL 1 HAS_DETAILED_LE_POWER_MODEL 1 HAS_DETAILED_ROUTING_MUX_STATIC_POWER_MODEL 1 HAS_DETAILED_THERMAL_CIRCUIT_PARAMETER_SUPPORT 1 HAS_DEVICE_MIGRATION_SUPPORT 1 HAS_DIAGONAL_MIGRATION_SUPPORT 0 HAS_EMIF_TOOLKIT_SUPPORT 0 HAS_ERROR_DETECTION_SUPPORT 0 HAS_FAMILY_VARIANT_MIGRATION_SUPPORT 0 HAS_FANOUT_FREE_NODE_SUPPORT 1 HAS_FAST_FIT_SUPPORT 1 HAS_FITTER_EARLY_TIMING_ESTIMATE_SUPPORT 1 HAS_FITTER_ECO_SUPPORT 1 HAS_FIT_NETLIST_OPT_RETIME_SUPPORT 1 HAS_FIT_NETLIST_OPT_SUPPORT 1 HAS_FORMAL_VERIFICATION_SUPPORT 1 HAS_FPGA_XCHANGE_SUPPORT 1 HAS_FSAC_LUTRAM_REGISTER_PACKING_SUPPORT 0 HAS_FULL_DAT_MIN_TIMING_SUPPORT 1 HAS_FULL_INCREMENTAL_DESIGN_SUPPORT 1 HAS_FUNCTIONAL_SIMULATION_SUPPORT 1 HAS_FUNCTIONAL_VERILOG_SIMULATION_SUPPORT 0 HAS_FUNCTIONAL_VHDL_SIMULATION_SUPPORT 0 HAS_GLITCH_FILTERING_SUPPORT 1 HAS_HC_READY_SUPPORT 0 HAS_HIGH_SPEED_LOW_POWER_TILE_SUPPORT 0 HAS_HOLD_TIME_AVOIDANCE_ACROSS_CLOCK_SPINE_SUPPORT 1 HAS_HSPICE_WRITER_SUPPORT 1 HAS_HSSI_POWER_CALCULATOR 0 HAS_IBISO_WRITER_SUPPORT 1 HAS_INCREMENTAL_DAT_SUPPORT 1 HAS_INCREMENTAL_SYNTHESIS_SUPPORT 1 HAS_INTERFACE_PLANNER_SUPPORT 0 HAS_IO_ASSIGNMENT_ANALYSIS_SUPPORT 1 HAS_IO_DECODER 0 HAS_IO_PLACEMENT_OPTIMIZATION_SUPPORT 1 HAS_IO_SMART_RECOMPILE_SUPPORT 0 HAS_JITTER_SUPPORT 1 HAS_JTAG_SLD_HUB_SUPPORT 1 HAS_LIMITED_TCL_FITTER_SUPPORT 0 HAS_LOGIC_LOCK_SUPPORT 1 HAS_MICROPROCESSOR 0 HAS_MIF_SMART_COMPILE_SUPPORT 1 HAS_MINMAX_TIMING_MODELING_SUPPORT 1 HAS_MIN_TIMING_ANALYSIS_SUPPORT 1 HAS_MUX_RESTRUCTURE_SUPPORT 1 HAS_NEW_HC_FLOW_SUPPORT 0 HAS_NEW_SERDES_MAX_RESOURCE_COUNT_REPORTING_SUPPORT 1 HAS_NEW_VPR_SUPPORT 1 HAS_NONSOCKET_TECHNOLOGY_MIGRATION_SUPPORT 0 HAS_NO_HARDBLOCK_PARTITION_SUPPORT 0 HAS_NO_JTAG_USERCODE_SUPPORT 0 HAS_OPERATING_SETTINGS_AND_CONDITIONS_REPORTING_SUPPORT 1 HAS_PAD_LOCATION_ASSIGNMENT_SUPPORT 0 HAS_PARTIAL_RECONFIG_SUPPORT 0 HAS_PHYSICAL_NETLIST_OUTPUT 0 HAS_PHYSICAL_ROUTING_SUPPORT 0 HAS_PIN_SPECIFIC_VOLTAGE_SUPPORT 1 HAS_PLDM_REF_SUPPORT 1 HAS_POWER_ESTIMATION_SUPPORT 1 HAS_PRELIMINARY_CLOCK_UNCERTAINTY_NUMBERS 0 HAS_PRE_FITTER_FPP_SUPPORT 0 HAS_PRE_FITTER_LUTRAM_NETLIST_CHECKER_ENABLED 0 HAS_PVA_SUPPORT 1 HAS_RCF_SUPPORT 1 HAS_RCF_SUPPORT_FOR_DEBUGGING 0 HAS_RED_BLACK_SEPARATION_SUPPORT 0 HAS_RE_LEVEL_TIMING_GRAPH_SUPPORT 1 HAS_RISEFALL_DELAY_SUPPORT 1 HAS_SIGNAL_PROBE_SUPPORT 1 HAS_SIGNAL_TAP_SUPPORT 1 HAS_SIMULATOR_SUPPORT 1 HAS_SPLIT_IO_SUPPORT 1 HAS_SPLIT_LC_SUPPORT 1 HAS_SYNTH_FSYN_NETLIST_OPT_SUPPORT 1 HAS_SYNTH_NETLIST_OPT_RETIME_SUPPORT 1 HAS_SYNTH_NETLIST_OPT_SUPPORT 1 HAS_TCL_FITTER_SUPPORT 0 HAS_TECHNOLOGY_MIGRATION_SUPPORT 0 HAS_TEMPLATED_REGISTER_PACKING_SUPPORT 1 HAS_TIME_BORROWING_SUPPORT 0 HAS_TIMING_DRIVEN_SYNTHESIS_SUPPORT 1 HAS_TIMING_INFO_SUPPORT 1 HAS_TIMING_OPERATING_CONDITIONS 1 HAS_TIMING_SIMULATION_SUPPORT 1 HAS_TITAN_BASED_MAC_REGISTER_PACKER_SUPPORT 0 HAS_U2B2_SUPPORT 0 HAS_USER_HIGH_SPEED_LOW_POWER_TILE_SUPPORT 0 HAS_USE_FITTER_INFO_SUPPORT 1 HAS_VCCPD_POWER_RAIL 0 HAS_VERTICAL_MIGRATION_SUPPORT 1 HAS_VIEWDRAW_SYMBOL_SUPPORT 0 HAS_VIO_SUPPORT 1 HAS_VIRTUAL_DEVICES 0 HAS_WYSIWYG_DFFEAS_SUPPORT 1 HAS_XIBISO_WRITER_SUPPORT 0 IFP_USE_LEGACY_IO_CHECKER 0 INCREMENTAL_DESIGN_SUPPORTS_COMPATIBLE_CONSTRAINTS 1 INSTALLED 0 IS_CONFIG_ROM 0 IS_DEFAULT_FAMILY 0 IS_HARDCOPY_FAMILY 0 LVDS_IO 0 M10K_MEMORY 0 M144K_MEMORY 0 M20K_MEMORY 0 M4K_MEMORY 0 M512_MEMORY 0 M9K_MEMORY 1 MLAB_MEMORY 0 MRAM_MEMORY 0 NOT_LISTED 0 NO_RPE_SUPPORT 0 NO_SUPPORT_FOR_LOGICLOCK_CONTENT_BACK_ANNOTATION 1 NO_SUPPORT_FOR_STA_CLOCK_UNCERTAINTY_CHECK 0 NO_TDC_SUPPORT 0 POSTFIT_BAK_DATABASE_EXPORT_ENABLED 1 POSTMAP_BAK_DATABASE_EXPORT_ENABLED 1 PROGRAMMER_SUPPORT 1 QFIT_IN_DEVELOPMENT 0 QMAP_IN_DEVELOPMENT 0 RAM_LOGICAL_NAME_CHECKING_IN_CUT_ENABLED 1 REPORTS_METASTABILITY_MTBF 1 REQUIRES_INSTALLATION_PATCH 0 REQUIRES_LIST_OF_TEMPERATURE_AND_VOLTAGE_OPERATING_CONDITIONS 1 RESERVES_SIGNAL_PROBE_PINS 0 RESOLVE_MAX_FANOUT_EARLY 1 RESOLVE_MAX_FANOUT_LATE 0 RESPECTS_FIXED_SIZED_LOCKED_LOCATION_LOGICLOCK 1 RESTRICTED_USER_SELECTION 0 RISEFALL_SUPPORT_IS_HIDDEN 0 STRICT_TIMING_DB_CHECKS 0 SUPPORTS_ADDITIONAL_OPTIONS_FOR_UNUSED_IO 0 SUPPORTS_CRC 1 SUPPORTS_DIFFERENTIAL_AIOT_BOARD_TRACE_MODEL 1 SUPPORTS_DSP_BALANCING_BACK_ANNOTATION 0 SUPPORTS_GENERATION_OF_EARLY_POWER_ESTIMATOR_FILE 1 SUPPORTS_GLOBAL_SIGNAL_BACK_ANNOTATION 0 SUPPORTS_MAC_CHAIN_OUT_ADDER 0 SUPPORTS_RAM_PACKING_BACK_ANNOTATION 0 SUPPORTS_REG_PACKING_BACK_ANNOTATION 0 SUPPORTS_SIGNALPROBE_REGISTER_PIPELINING 1 SUPPORTS_SINGLE_ENDED_AIOT_BOARD_TRACE_MODEL 1 SUPPORTS_USER_MANUAL_LOGIC_DUPLICATION 1 TMV_RUN_CUSTOMIZABLE_VIEWER 1 TMV_RUN_INTERNAL_DETAILS 1 TMV_RUN_INTERNAL_DETAILS_ON_IO 0 TMV_RUN_INTERNAL_DETAILS_ON_IOBUF 1 TMV_RUN_INTERNAL_DETAILS_ON_LCELL 0 TMV_RUN_INTERNAL_DETAILS_ON_LRAM 0 TRANSCEIVER_3G_BLOCK 0 TRANSCEIVER_6G_BLOCK 0 USES_ACV_FOR_FLED 1 USES_ADB_FOR_BACK_ANNOTATION 1 USES_ALTERA_LNSIM 0 USES_ASIC_ROUTING_POWER_CALCULATOR 0 USES_DATA_DRIVEN_PLL_COMPUTATION_UTIL 1 USES_DEV 1 USES_ICP_FOR_ECO_FITTER 0 USES_LIBERTY_TIMING 0 USES_POWER_SIGNAL_ACTIVITIES 1 USES_THIRD_GENERATION_TIMING_MODELS_TIS 1 USES_U2B2_TIMING_MODELS 0 USE_ADVANCED_IO_POWER_BY_DEFAULT 1 USE_ADVANCED_IO_TIMING_BY_DEFAULT 1 USE_BASE_FAMILY_DDB_PATH 0 USE_OCT_AUTO_CALIBRATION 0 USE_RELAX_IO_ASSIGNMENT_RULES 1 USE_RISEFALL_ONLY 1 USE_SEPARATE_LIST_FOR_TECH_MIGRATION 0 USE_SINGLE_COMPILER_PASS_PLL_MIF_FILE_WRITER 1 USE_TITAN_IO_BASED_IO_REGISTER_PACKER_UTIL 0 WYSIWYG_BUS_WIDTH_CHECKING_IN_CUT_ENABLED 1
tightlyCoupledDataMaster0MapParam
tightlyCoupledDataMaster1MapParam
tightlyCoupledDataMaster2MapParam
tightlyCoupledDataMaster3MapParam
tightlyCoupledInstructionMaster0MapParam
tightlyCoupledInstructionMaster1MapParam
tightlyCoupledInstructionMaster2MapParam
tightlyCoupledInstructionMaster3MapParam
deviceFamily | UNKNOWN
generateLegacySim | false

Software Assignments

BIG_ENDIAN | 0
BREAK_ADDR | 0x01810820
CPU_FREQ | 50000000u
CPU_ID_SIZE | 1
CPU_ID_VALUE | 0x00000000
CPU_IMPLEMENTATION | "fast"
DATA_ADDR_WIDTH | 25
DCACHE_LINE_SIZE | 32
DCACHE_LINE_SIZE_LOG2 | 5
DCACHE_SIZE | 2048
EXCEPTION_ADDR | 0x0180c020
FLUSHDA_SUPPORTED
HARDWARE_DIVIDE_PRESENT | 1
HARDWARE_MULTIPLY_PRESENT | 1
HARDWARE_MULX_PRESENT | 0
HAS_DEBUG_CORE | 1
HAS_DEBUG_STUB
HAS_JMPI_INSTRUCTION
ICACHE_LINE_SIZE | 32
ICACHE_LINE_SIZE_LOG2 | 5
ICACHE_SIZE | 4096
INITDA_SUPPORTED
INST_ADDR_WIDTH | 25
NUM_OF_SHADOW_REG_SETS | 0
RESET_ADDR | 0x0180c000

## onchip_memory2_0

altera_avalon_onchip_memory2 v13.0.1.99.2

clk_0 | clk | onchip_memory2_0
| clk1
| clk_reset
| reset1
nios2_qsys_0 | instruction_master
| s1
| data_master
| s1
| jtag_debug_module_reset
| reset1

Parameters

allowInSystemMemoryContentEditor | false
blockType | AUTO
dataWidth | 32
dualPort | false
initMemContent | true
initializationFileName | onchip_mem.hex
instanceID | NONE
memorySize | 16384
readDuringWriteMode | DONT_CARE
simAllowMRAMContentsFile | false
simMemInitOnlyFilename | 0
singleClockOperation | false
slave1Latency | 1
slave2Latency | 1
useNonDefaultInitFile | false
useShallowMemBlocks | false
writable | true
autoInitializationFileName | NiosII_ps2_onchip_memory2_0
deviceFamily | CYCLONEIII

deviceFeatures

ADDRESS_STALL 1 CELL_LEVEL_BACK_ANNOTATION_DISABLED 0 COMPILER_SUPPORT 1 DSP 0 DSP_SHIFTER_BLOCK 0 DUMP_ASM_LAB_BITS_FOR_POWER 1 EMUL 1 ENABLE_ADVANCED_IO_ANALYSIS_GUI_FEATURES 1 EPCS 1 ESB 0 FAKE1 0 FAKE2 0 FAKE3 0 FAMILY_LEVEL_INSTALLATION_ONLY 1 FITTER_USE_FALLING_EDGE_DELAY 1 GENERATE_DC_ON_CURRENT_WARNING_FOR_INTERNAL_CLAMPING_DIODE 0 HARDCOPY 0 HAS_18_BIT_MULTS 0 HAS_ACE_SUPPORT 1 HAS_ADJUSTABLE_OUTPUT_IO_TIMING_MEAS_POINT 1 HAS_ADVANCED_IO_INVERTED_CORNER 0 HAS_ADVANCED_IO_POWER_SUPPORT 1 HAS_ADVANCED_IO_TIMING_SUPPORT 1 HAS_ALM_SUPPORT 0 HAS_ATOM_AND_ROUTING_POWER_MODELED_TOGETHER 0 HAS_AUTO_DERIVE_CLOCK_UNCERTAINTY_SUPPORT 0 HAS_AUTO_FIT_SUPPORT 1 HAS_BALANCED_OPT_TECHNIQUE_SUPPORT 1 HAS_BENEFICIAL_SKEW_SUPPORT 1 HAS_BITLEVEL_DRIVE_STRENGTH_CONTROL 1 HAS_BSDL_FILE_GENERATION 0 HAS_CGA_SUPPORT 1 HAS_CHECK_NETLIST_SUPPORT 0 HAS_CLOCK_REGION_CHECKER_ENABLED 1 HAS_CORE_JUNCTION_TEMP_DERATING 0 HAS_CROSSTALK_SUPPORT 0 HAS_CUSTOM_REGION_SUPPORT 1 HAS_DAP_JTAG_FROM_HPS 0 HAS_DATA_DRIVEN_ACVQ_HSSI_SUPPORT 0 HAS_DDB_FDI_SUPPORT 0 HAS_DESIGN_ANALYZER_SUPPORT 1 HAS_DETAILED_IO_RAIL_POWER_MODEL 1 HAS_DETAILED_LEIM_STATIC_POWER_MODEL 1 HAS_DETAILED_LE_POWER_MODEL 1 HAS_DETAILED_ROUTING_MUX_STATIC_POWER_MODEL 1 HAS_DETAILED_THERMAL_CIRCUIT_PARAMETER_SUPPORT 1 HAS_DEVICE_MIGRATION_SUPPORT 1 HAS_DIAGONAL_MIGRATION_SUPPORT 0 HAS_EMIF_TOOLKIT_SUPPORT 0 HAS_ERROR_DETECTION_SUPPORT 0 HAS_FAMILY_VARIANT_MIGRATION_SUPPORT 0 HAS_FANOUT_FREE_NODE_SUPPORT 1 HAS_FAST_FIT_SUPPORT 1 HAS_FITTER_EARLY_TIMING_ESTIMATE_SUPPORT 1 HAS_FITTER_ECO_SUPPORT 1 HAS_FIT_NETLIST_OPT_RETIME_SUPPORT 1 HAS_FIT_NETLIST_OPT_SUPPORT 1 HAS_FORMAL_VERIFICATION_SUPPORT 1 HAS_FPGA_XCHANGE_SUPPORT 1 HAS_FSAC_LUTRAM_REGISTER_PACKING_SUPPORT 0 HAS_FULL_DAT_MIN_TIMING_SUPPORT 1 HAS_FULL_INCREMENTAL_DESIGN_SUPPORT 1 HAS_FUNCTIONAL_SIMULATION_SUPPORT 1 HAS_FUNCTIONAL_VERILOG_SIMULATION_SUPPORT 0 HAS_FUNCTIONAL_VHDL_SIMULATION_SUPPORT 0 HAS_GLITCH_FILTERING_SUPPORT 1 HAS_HC_READY_SUPPORT 0 HAS_HIGH_SPEED_LOW_POWER_TILE_SUPPORT 0 HAS_HOLD_TIME_AVOIDANCE_ACROSS_CLOCK_SPINE_SUPPORT 1 HAS_HSPICE_WRITER_SUPPORT 1 HAS_HSSI_POWER_CALCULATOR 0 HAS_IBISO_WRITER_SUPPORT 1 HAS_INCREMENTAL_DAT_SUPPORT 1 HAS_INCREMENTAL_SYNTHESIS_SUPPORT 1 HAS_INTERFACE_PLANNER_SUPPORT 0 HAS_IO_ASSIGNMENT_ANALYSIS_SUPPORT 1 HAS_IO_DECODER 0 HAS_IO_PLACEMENT_OPTIMIZATION_SUPPORT 1 HAS_IO_SMART_RECOMPILE_SUPPORT 0 HAS_JITTER_SUPPORT 1 HAS_JTAG_SLD_HUB_SUPPORT 1 HAS_LIMITED_TCL_FITTER_SUPPORT 0 HAS_LOGIC_LOCK_SUPPORT 1 HAS_MICROPROCESSOR 0 HAS_MIF_SMART_COMPILE_SUPPORT 1 HAS_MINMAX_TIMING_MODELING_SUPPORT 1 HAS_MIN_TIMING_ANALYSIS_SUPPORT 1 HAS_MUX_RESTRUCTURE_SUPPORT 1 HAS_NEW_HC_FLOW_SUPPORT 0 HAS_NEW_SERDES_MAX_RESOURCE_COUNT_REPORTING_SUPPORT 1 HAS_NEW_VPR_SUPPORT 1 HAS_NONSOCKET_TECHNOLOGY_MIGRATION_SUPPORT 0 HAS_NO_HARDBLOCK_PARTITION_SUPPORT 0 HAS_NO_JTAG_USERCODE_SUPPORT 0 HAS_OPERATING_SETTINGS_AND_CONDITIONS_REPORTING_SUPPORT 1 HAS_PAD_LOCATION_ASSIGNMENT_SUPPORT 0 HAS_PARTIAL_RECONFIG_SUPPORT 0 HAS_PHYSICAL_NETLIST_OUTPUT 0 HAS_PHYSICAL_ROUTING_SUPPORT 0 HAS_PIN_SPECIFIC_VOLTAGE_SUPPORT 1 HAS_PLDM_REF_SUPPORT 1 HAS_POWER_ESTIMATION_SUPPORT 1 HAS_PRELIMINARY_CLOCK_UNCERTAINTY_NUMBERS 0 HAS_PRE_FITTER_FPP_SUPPORT 0 HAS_PRE_FITTER_LUTRAM_NETLIST_CHECKER_ENABLED 0 HAS_PVA_SUPPORT 1 HAS_RCF_SUPPORT 1 HAS_RCF_SUPPORT_FOR_DEBUGGING 0 HAS_RED_BLACK_SEPARATION_SUPPORT 0 HAS_RE_LEVEL_TIMING_GRAPH_SUPPORT 1 HAS_RISEFALL_DELAY_SUPPORT 1 HAS_SIGNAL_PROBE_SUPPORT 1 HAS_SIGNAL_TAP_SUPPORT 1 HAS_SIMULATOR_SUPPORT 1 HAS_SPLIT_IO_SUPPORT 1 HAS_SPLIT_LC_SUPPORT 1 HAS_SYNTH_FSYN_NETLIST_OPT_SUPPORT 1 HAS_SYNTH_NETLIST_OPT_RETIME_SUPPORT 1 HAS_SYNTH_NETLIST_OPT_SUPPORT 1 HAS_TCL_FITTER_SUPPORT 0 HAS_TECHNOLOGY_MIGRATION_SUPPORT 0 HAS_TEMPLATED_REGISTER_PACKING_SUPPORT 1 HAS_TIME_BORROWING_SUPPORT 0 HAS_TIMING_DRIVEN_SYNTHESIS_SUPPORT 1 HAS_TIMING_INFO_SUPPORT 1 HAS_TIMING_OPERATING_CONDITIONS 1 HAS_TIMING_SIMULATION_SUPPORT 1 HAS_TITAN_BASED_MAC_REGISTER_PACKER_SUPPORT 0 HAS_U2B2_SUPPORT 0 HAS_USER_HIGH_SPEED_LOW_POWER_TILE_SUPPORT 0 HAS_USE_FITTER_INFO_SUPPORT 1 HAS_VCCPD_POWER_RAIL 0 HAS_VERTICAL_MIGRATION_SUPPORT 1 HAS_VIEWDRAW_SYMBOL_SUPPORT 0 HAS_VIO_SUPPORT 1 HAS_VIRTUAL_DEVICES 0 HAS_WYSIWYG_DFFEAS_SUPPORT 1 HAS_XIBISO_WRITER_SUPPORT 0 IFP_USE_LEGACY_IO_CHECKER 0 INCREMENTAL_DESIGN_SUPPORTS_COMPATIBLE_CONSTRAINTS 1 INSTALLED 0 IS_CONFIG_ROM 0 IS_DEFAULT_FAMILY 0 IS_HARDCOPY_FAMILY 0 LVDS_IO 0 M10K_MEMORY 0 M144K_MEMORY 0 M20K_MEMORY 0 M4K_MEMORY 0 M512_MEMORY 0 M9K_MEMORY 1 MLAB_MEMORY 0 MRAM_MEMORY 0 NOT_LISTED 0 NO_RPE_SUPPORT 0 NO_SUPPORT_FOR_LOGICLOCK_CONTENT_BACK_ANNOTATION 1 NO_SUPPORT_FOR_STA_CLOCK_UNCERTAINTY_CHECK 0 NO_TDC_SUPPORT 0 POSTFIT_BAK_DATABASE_EXPORT_ENABLED 1 POSTMAP_BAK_DATABASE_EXPORT_ENABLED 1 PROGRAMMER_SUPPORT 1 QFIT_IN_DEVELOPMENT 0 QMAP_IN_DEVELOPMENT 0 RAM_LOGICAL_NAME_CHECKING_IN_CUT_ENABLED 1 REPORTS_METASTABILITY_MTBF 1 REQUIRES_INSTALLATION_PATCH 0 REQUIRES_LIST_OF_TEMPERATURE_AND_VOLTAGE_OPERATING_CONDITIONS 1 RESERVES_SIGNAL_PROBE_PINS 0 RESOLVE_MAX_FANOUT_EARLY 1 RESOLVE_MAX_FANOUT_LATE 0 RESPECTS_FIXED_SIZED_LOCKED_LOCATION_LOGICLOCK 1 RESTRICTED_USER_SELECTION 0 RISEFALL_SUPPORT_IS_HIDDEN 0 STRICT_TIMING_DB_CHECKS 0 SUPPORTS_ADDITIONAL_OPTIONS_FOR_UNUSED_IO 0 SUPPORTS_CRC 1 SUPPORTS_DIFFERENTIAL_AIOT_BOARD_TRACE_MODEL 1 SUPPORTS_DSP_BALANCING_BACK_ANNOTATION 0 SUPPORTS_GENERATION_OF_EARLY_POWER_ESTIMATOR_FILE 1 SUPPORTS_GLOBAL_SIGNAL_BACK_ANNOTATION 0 SUPPORTS_MAC_CHAIN_OUT_ADDER 0 SUPPORTS_RAM_PACKING_BACK_ANNOTATION 0 SUPPORTS_REG_PACKING_BACK_ANNOTATION 0 SUPPORTS_SIGNALPROBE_REGISTER_PIPELINING 1 SUPPORTS_SINGLE_ENDED_AIOT_BOARD_TRACE_MODEL 1 SUPPORTS_USER_MANUAL_LOGIC_DUPLICATION 1 TMV_RUN_CUSTOMIZABLE_VIEWER 1 TMV_RUN_INTERNAL_DETAILS 1 TMV_RUN_INTERNAL_DETAILS_ON_IO 0 TMV_RUN_INTERNAL_DETAILS_ON_IOBUF 1 TMV_RUN_INTERNAL_DETAILS_ON_LCELL 0 TMV_RUN_INTERNAL_DETAILS_ON_LRAM 0 TRANSCEIVER_3G_BLOCK 0 TRANSCEIVER_6G_BLOCK 0 USES_ACV_FOR_FLED 1 USES_ADB_FOR_BACK_ANNOTATION 1 USES_ALTERA_LNSIM 0 USES_ASIC_ROUTING_POWER_CALCULATOR 0 USES_DATA_DRIVEN_PLL_COMPUTATION_UTIL 1 USES_DEV 1 USES_ICP_FOR_ECO_FITTER 0 USES_LIBERTY_TIMING 0 USES_POWER_SIGNAL_ACTIVITIES 1 USES_THIRD_GENERATION_TIMING_MODELS_TIS 1 USES_U2B2_TIMING_MODELS 0 USE_ADVANCED_IO_POWER_BY_DEFAULT 1 USE_ADVANCED_IO_TIMING_BY_DEFAULT 1 USE_BASE_FAMILY_DDB_PATH 0 USE_OCT_AUTO_CALIBRATION 0 USE_RELAX_IO_ASSIGNMENT_RULES 1 USE_RISEFALL_ONLY 1 USE_SEPARATE_LIST_FOR_TECH_MIGRATION 0 USE_SINGLE_COMPILER_PASS_PLL_MIF_FILE_WRITER 1 USE_TITAN_IO_BASED_IO_REGISTER_PACKER_UTIL 0 WYSIWYG_BUS_WIDTH_CHECKING_IN_CUT_ENABLED 1
derived_set_addr_width | 12
derived_gui_ram_block_type | Automatic
derived_is_hardcopy | false
derived_init_file_name | NiosII_ps2_onchip_memory2_0.hex
generateLegacySim | false

Software Assignments

ALLOW_IN_SYSTEM_MEMORY_CONTENT_EDITOR | 0
ALLOW_MRAM_SIM_CONTENTS_ONLY_FILE | 0
CONTENTS_INFO | ""
DUAL_PORT | 0
GUI_RAM_BLOCK_TYPE | AUTO
INIT_CONTENTS_FILE | NiosII_ps2_onchip_memory2_0
INIT_MEM_CONTENT | 1
INSTANCE_ID | NONE
NON_DEFAULT_INIT_FILE_ENABLED | 0
RAM_BLOCK_TYPE | AUTO
READ_DURING_WRITE_MODE | DONT_CARE
SINGLE_CLOCK_OP | 0
SIZE_MULTIPLE | 1
SIZE_VALUE | 16384
WRITABLE | 1

## jtag_uart_0

altera_avalon_jtag_uart v13.0.1.99.2

clk_0 | clk | jtag_uart_0
| clk
| clk_reset
| reset
nios2_qsys_0 | data_master
| avalon_jtag_slave
| d_irq
| irq
| jtag_debug_module_reset
| reset
| instruction_master
| avalon_jtag_slave

Parameters

allowMultipleConnections | false
hubInstanceID | 0
readBufferDepth | 64
readIRQThreshold | 8
simInputCharacterStream
simInteractiveOptions | NO_INTERACTIVE_WINDOWS
useRegistersForReadBuffer | false
useRegistersForWriteBuffer | false
useRelativePathForSimFile | false
writeBufferDepth | 64
writeIRQThreshold | 8
avalonSpec | 2.0
legacySignalAllow | false
enableInteractiveInput | false
enableInteractiveOutput | false
deviceFamily | UNKNOWN
generateLegacySim | false

Software Assignments

READ_DEPTH | 64
READ_THRESHOLD | 8
WRITE_DEPTH | 64
WRITE_THRESHOLD | 8

## pio_0

altera_avalon_pio v13.0.1.99.2

clk_0 | clk | pio_0
| clk
| clk_reset
| reset
nios2_qsys_0 | data_master
| s1
| jtag_debug_module_reset
| reset
| instruction_master
| s1

Parameters

bitClearingEdgeCapReg | false
bitModifyingOutReg | false
captureEdge | false
direction | Input
edgeType | RISING
generateIRQ | false
irqType | LEVEL
resetValue | 0
simDoTestBenchWiring | false
simDrivenValue | 0
width | 4
clockRate | 50000000
derived_has_tri | false
derived_has_out | false
derived_has_in | true
derived_do_test_bench_wiring | false
derived_capture | false
derived_edge_type | NONE
derived_irq_type | NONE
derived_has_irq | false
deviceFamily | UNKNOWN
generateLegacySim | false

Software Assignments

BIT_CLEARING_EDGE_REGISTER | 0
BIT_MODIFYING_OUTPUT_REGISTER | 0
CAPTURE | 0
DATA_WIDTH | 4
DO_TEST_BENCH_WIRING | 0
DRIVEN_SIM_VALUE | 0
EDGE_TYPE | NONE
FREQ | 50000000
HAS_IN | 1
HAS_OUT | 0
HAS_TRI | 0
IRQ_TYPE | NONE
RESET_VALUE | 0

## led_matrix_avalon_0

led_matrix_avalon v1.0

clk_0 | clk | led_matrix_avalon_0
| clock
| clk_reset
| reset_n
nios2_qsys_0 | data_master
| avalon_slave
| jtag_debug_module_reset
| reset_n
| instruction_master
| avalon_slave

Parameters

WIDTH_PIXELS | 128
HEIGHT_PIXELS | 64
AUTO_CLOCK_CLOCK_RATE | 50000000
deviceFamily | UNKNOWN
generateLegacySim | false

Software Assignments
(none)

## sysid_qsys_0

altera_avalon_sysid_qsys v13.0

clk_0 | clk | sysid_qsys_0
| clk
| clk_reset
| reset
nios2_qsys_0 | data_master
| control_slave
| instruction_master
| control_slave
| jtag_debug_module_reset
| reset

Parameters

id | 0
timestamp | 1776110056
AUTO_CLK_CLOCK_RATE | 50000000
AUTO_DEVICE_FAMILY | CYCLONEIII
deviceFamily | Cyclone III
generateLegacySim | false

Software Assignments

ID | 0
TIMESTAMP | 1776110056

## ps2_interface_0

ps2_interface v1.0

clk_0 | clk | ps2_interface_0
| clock
| clk_reset
| reset
nios2_qsys_0 | data_master
| avalon_slave_0
| jtag_debug_module_reset
| reset
| instruction_master
| avalon_slave_0

Parameters

AUTO_CLOCK_CLOCK_RATE | 50000000
deviceFamily | UNKNOWN
generateLegacySim | false

Software Assignments
(none)

## new_sdram_controller_0

altera_avalon_new_sdram_controller v13.0.1.99.2

clk_0 | clk | new_sdram_controller_0
| clk
| clk_reset
| reset
nios2_qsys_0 | instruction_master
| s1
| data_master
| s1
| jtag_debug_module_reset
| reset

Parameters

TAC | 5.5
TRCD | 20.0
TRFC | 70.0
TRP | 20.0
TWR | 14.0
casLatency | 3
columnWidth | 8
dataWidth | 16
generateSimulationModel | false
initRefreshCommands | 2
model | single_Micron_MT48LC4M32B2_7_chip
numberOfBanks | 4
numberOfChipSelects | 1
pinsSharedViaTriState | false
powerUpDelay | 100.0
refreshPeriod | 7.8125
rowWidth | 12
masteredTristateBridgeSlave | 0
TMRD | 3
initNOPDelay | 0.0
registerDataIn | true
clockRate | 50000000
componentName | NiosII_ps2_new_sdram_controller_0
size | 8388608
addressWidth | 22
bankWidth | 2
deviceFamily | UNKNOWN
generateLegacySim | false

Software Assignments

CAS_LATENCY | 3
CONTENTS_INFO
INIT_NOP_DELAY | 0.0
INIT_REFRESH_COMMANDS | 2
IS_INITIALIZED | 1
POWERUP_DELAY | 100.0
REFRESH_PERIOD | 7.8125
REGISTER_DATA_IN | 1
SDRAM_ADDR_WIDTH | 22
SDRAM_BANK_WIDTH | 2
SDRAM_COL_WIDTH | 8
SDRAM_DATA_WIDTH | 16
SDRAM_NUM_BANKS | 4
SDRAM_NUM_CHIPSELECTS | 1
SDRAM_ROW_WIDTH | 12
SHARED_DATA | 0
SIM_MODEL_BASE | 0
STARVATION_INDICATOR | 0
TRISTATE_BRIDGE_SLAVE | ""
T_AC | 5.5
T_MRD | 3
T_RCD | 20.0
T_RFC | 70.0
T_RP | 20.0
T_WR | 14.0

## i2c_clk

altera_avalon_pio v13.0.1.99.2

clk_0 | clk | i2c_clk
| clk
| clk_reset
| reset
nios2_qsys_0 | data_master
| s1
| instruction_master
| s1
| jtag_debug_module_reset
| reset

Parameters

bitClearingEdgeCapReg | false
bitModifyingOutReg | false
captureEdge | false
direction | Output
edgeType | RISING
generateIRQ | false
irqType | LEVEL
resetValue | 0
simDoTestBenchWiring | false
simDrivenValue | 0
width | 1
clockRate | 50000000
derived_has_tri | false
derived_has_out | true
derived_has_in | false
derived_do_test_bench_wiring | false
derived_capture | false
derived_edge_type | NONE
derived_irq_type | NONE
derived_has_irq | false
deviceFamily | UNKNOWN
generateLegacySim | false

Software Assignments

BIT_CLEARING_EDGE_REGISTER | 0
BIT_MODIFYING_OUTPUT_REGISTER | 0
CAPTURE | 0
DATA_WIDTH | 1
DO_TEST_BENCH_WIRING | 0
DRIVEN_SIM_VALUE | 0
EDGE_TYPE | NONE
FREQ | 50000000
HAS_IN | 0
HAS_OUT | 1
HAS_TRI | 0
IRQ_TYPE | NONE
RESET_VALUE | 0

## i2c_sda

altera_avalon_pio v13.0.1.99.2

clk_0 | clk | i2c_sda
| clk
| clk_reset
| reset
nios2_qsys_0 | jtag_debug_module_reset
| reset
| instruction_master
| s1
| data_master
| s1

Parameters

bitClearingEdgeCapReg | false
bitModifyingOutReg | false
captureEdge | false
direction | Bidir
edgeType | RISING
generateIRQ | false
irqType | LEVEL
resetValue | 0
simDoTestBenchWiring | false
simDrivenValue | 0
width | 1
clockRate | 50000000
derived_has_tri | true
derived_has_out | false
derived_has_in | false
derived_do_test_bench_wiring | false
derived_capture | false
derived_edge_type | NONE
derived_irq_type | NONE
derived_has_irq | false
deviceFamily | UNKNOWN
generateLegacySim | false

Software Assignments

BIT_CLEARING_EDGE_REGISTER | 0
BIT_MODIFYING_OUTPUT_REGISTER | 0
CAPTURE | 0
DATA_WIDTH | 1
DO_TEST_BENCH_WIRING | 0
DRIVEN_SIM_VALUE | 0
EDGE_TYPE | NONE
FREQ | 50000000
HAS_IN | 0
HAS_OUT | 0
HAS_TRI | 1
IRQ_TYPE | NONE
RESET_VALUE | 0

## uart_0

altera_avalon_uart v13.0.1.99.2

clk_0 | clk | uart_0
| clk
| clk_reset
| reset
nios2_qsys_0 | jtag_debug_module_reset
| reset
| data_master
| s1
| d_irq
| irq

Parameters

baud | 9600
dataBits | 8
fixedBaud | true
parity | NONE
simCharStream
simInteractiveInputEnable | false
simInteractiveOutputEnable | false
simTrueBaud | false
stopBits | 1
syncRegDepth | 2
useCtsRts | false
useEopRegister | false
useRelativePathForSimFile | false
clockRate | 50000000
baudError | 0.01
parityFisrtChar | N
deviceFamily | UNKNOWN
generateLegacySim | false

Software Assignments

BAUD | 9600
DATA_BITS | 8
FIXED_BAUD | 1
FREQ | 50000000
PARITY | 'N'
SIM_CHAR_STREAM | ""
SIM_TRUE_BAUD | 0
STOP_BITS | 1
SYNC_REG_DEPTH | 2
USE_CTS_RTS | 0
USE_EOP_REGISTER | 0

## sd_spi_0

altera_avalon_spi v13.0.1.99.2

clk_0 | clk | sd_spi_0
| clk
| clk_reset
| reset
nios2_qsys_0 | jtag_debug_module_reset
| reset
| d_irq
| irq
| data_master
| spi_control_port

Parameters

clockPhase | 0
clockPolarity | 0
dataWidth | 8
disableAvalonFlowControl | false
insertDelayBetweenSlaveSelectAndSClk | false
insertSync | false
lsbOrderedFirst | false
masterSPI | true
numberOfSlaves | 1
syncRegDepth | 2
targetClockRate | 128000
targetSlaveSelectToSClkDelay | 0.0
avalonSpec | 2.0
inputClockRate | 50000000
actualClockRate | 127551.0
actualSlaveSelectToSClkDelay | 0.0
legacySignalsAllow | false
slaveDataBusWidth | 16
deviceFamily | UNKNOWN
generateLegacySim | false

Software Assignments

CLOCKMULT | 1
CLOCKPHASE | 0
CLOCKPOLARITY | 0
CLOCKUNITS | "Hz"
DATABITS | 8
DATAWIDTH | 16
DELAYMULT | "1.0E-9"
DELAYUNITS | "ns"
EXTRADELAY | 0
INSERT_SYNC | 0
ISMASTER | 1
LSBFIRST | 0
NUMSLAVES | 1
PREFIX | "spi_"
SYNC_REG_DEPTH | 2
TARGETCLOCK | 128000u
TARGETSSDELAY | "0.0"

## generic_tristate_controller_0

altera_generic_tristate_controller v13.0

clk_0 | clk | generic_tristate_controller_0
| clk
| clk_reset
| reset
nios2_qsys_0 | jtag_debug_module_reset
| reset
| data_master
| uas
| instruction_master
| uas

Parameters

TCM_ADDRESS_W | 22
TCM_DATA_W | 8
TCM_BYTEENABLE_W | 1
TCM_READ_WAIT | 160
TCM_WRITE_WAIT | 160
TCM_SETUP_WAIT | 40
TCM_DATA_HOLD | 40
TCM_MAX_PENDING_READ_TRANSACTIONS | 3
TCM_TURNAROUND_TIME | 2
TCM_TIMING_UNITS | 0
TCM_READLATENCY | 2
TCM_SYMBOLS_PER_WORD | 1
USE_READDATA | 1
USE_WRITEDATA | 1
USE_READ | 1
USE_WRITE | 1
USE_BEGINTRANSFER | 0
USE_BYTEENABLE | 0
USE_CHIPSELECT | 1
USE_LOCK | 0
USE_ADDRESS | 1
USE_WAITREQUEST | 0
USE_WRITEBYTEENABLE | 0
USE_OUTPUTENABLE | 0
USE_RESETREQUEST | 0
USE_IRQ | 0
USE_RESET_OUTPUT | 0
ACTIVE_LOW_READ | 1
ACTIVE_LOW_LOCK | 0
ACTIVE_LOW_WRITE | 1
ACTIVE_LOW_CHIPSELECT | 1
ACTIVE_LOW_BYTEENABLE | 0
ACTIVE_LOW_OUTPUTENABLE | 0
ACTIVE_LOW_WRITEBYTEENABLE | 0
ACTIVE_LOW_WAITREQUEST | 0
ACTIVE_LOW_BEGINTRANSFER | 0
ACTIVE_LOW_RESETREQUEST | 0
ACTIVE_LOW_IRQ | 0
ACTIVE_LOW_RESET_OUTPUT | 0
CHIPSELECT_THROUGH_READLATENCY | 0
IS_MEMORY_DEVICE | 1
MODULE_ASSIGNMENT_KEYS | embeddedsw.configuration.hwClassnameDriverSupportList,embeddedsw.configuration.hwClassnameDriverSupportDefault,embeddedsw.CMacro.SETUP_VALUE,embeddedsw.CMacro.WAIT_VALUE,embeddedsw.CMacro.HOLD_VALUE,embeddedsw.CMacro.TIMING_UNITS,embeddedsw.CMacro.SIZE,embeddedsw.memoryInfo.MEM_INIT_DATA_WIDTH,embeddedsw.memoryInfo.HAS_BYTE_LANE,embeddedsw.memoryInfo.IS_FLASH,embeddedsw.memoryInfo.GENERATE_DAT_SYM,embeddedsw.memoryInfo.GENERATE_FLASH,embeddedsw.memoryInfo.DAT_SYM_INSTALL_DIR,embeddedsw.memoryInfo.FLASH_INSTALL_DIR
MODULE_ASSIGNMENT_VALUES | altera_avalon_lan91c111:altera_avalon_cfi_flash,altera_avalon_cfi_flash,0,0,0,ns,262144u,8,0,1,1,1,SIM_DIR,APP_DIR
INTERFACE_ASSIGNMENT_KEYS | embeddedsw.configuration.isFlash,embeddedsw.configuration.isMemoryDevice,embeddedsw.configuration.isNonVolatileStorage
INTERFACE_ASSIGNMENT_VALUES | 1,1,1
CLOCK_RATE | 50000000
AUTO_CLK_CLOCK_DOMAIN | 1
AUTO_CLK_RESET_DOMAIN | 1
AUTO_TRISTATECONDUIT_MASTERS
AUTO_DEVICE_FAMILY | CYCLONEIII
AUTO_DEVICE | EP3C16F484C6
deviceFamily | Cyclone III
generateLegacySim | false

Software Assignments

HOLD_VALUE | 0
SETUP_VALUE | 0
SIZE | 262144u
TIMING_UNITS | ns
WAIT_VALUE | 0

generation took 0,01 seconds | rendering took 0,20 seconds

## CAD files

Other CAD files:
hardware/NiosII_ps2/synthesis/stp1_auto_stripped.stp
hardware/NiosII_ps2/synthesis/stp1.stp
hardware/NiosII_ps2/synthesis/stp2_auto_stripped.stp
hardware/NiosII_ps2/synthesis/stp2.stp
hardware/NiosII_ps2/synthesis/stp3_auto_stripped.stp
hardware/NiosII_ps2/synthesis/stp3.stp

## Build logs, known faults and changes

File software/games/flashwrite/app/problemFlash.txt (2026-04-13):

Esse comportamento onde a memória falha exatamente ao atingir o bit A15 = 1 (o que corresponde à marca de 32 KBytes no barramento de endereços) é um sintoma muito clássico em projetos com o Nios II e memórias Flash.

Existem três motivos principais que causam esse problema específico, sendo o primeiro o mais provável para a placa DE0.

1. Interferência do Cache de Dados do Nios II (Causa mais provável)
O processador Nios II (na versão /f) frequentemente é configurado com um cache de dados em hardware de 16 KB ou 32 KB. O uso de ponteiros volatile no seu código em C não faz o bypass do cache no Nios II.

O que acontece: Quando o seu código atinge o endereço 0x8000 (A15 = 1, ou seja, 32 KB de deslocamento), o endereço entra em conflito (alias) com a linha zero do cache. Para carregar o novo endereço, o Nios II faz um cache eviction (despejo de cache), forçando uma escrita automática em rajada na memória Flash para salvar os dados antigos de volta na memória.

O Erro: Se esse eviction ocorrer exatamente no meio da sua sequência de comandos CFI (por exemplo, entre o segundo ciclo de Unlock e a escrita do comando de Erase), essa escrita em rajada indesejada interrompe e corrompe a máquina de estados do controlador da Flash. O comando falha silenciosamente e a memória não apaga.

Como resolver: Você nunca deve acessar a Flash usando ponteiros comuns ao enviar comandos CFI. Utilize as macros de leitura e escrita direta da biblioteca <io.h> do HAL da Altera/Intel, que ignoram o cache de dados:

C
#include "io.h"

// Para escrever comandos CFI (faz o bypass do cache do Nios II)
IOWR_16DIRECT(FLASH_BASE, offset_em_bytes, dado);

// Para ler dados ou ler o status de Polling
IORD_16DIRECT(FLASH_BASE, offset_em_bytes);
2. Configuração do Address Span no Qsys (Platform Designer)
Se você estiver utilizando um controlador como o Generic Tri-State Controller ou Avalon-MM Tristate para fazer a interface do Avalon com os pinos da Flash, verifique o tamanho da memória mapeada no Qsys.

O que acontece: É muito comum esquecer de alterar o tamanho padrão do componente. Se ele foi configurado para 32 KBytes (que exige apenas 15 bits de endereço), o barramento Avalon não consegue rotear endereços maiores.

O Erro: A sequência de Erase exige um último ciclo onde você escreve o comando 0x30 diretamente no endereço base do setor. Se você tentar enviar esse comando para um setor onde A15=1, o barramento Avalon não encaminha a escrita para a Flash. A Flash fica travada esperando a conclusão do comando.

Como resolver: Abra seu projeto no Qsys, dê um duplo clique no controlador Tristate da Flash e garanta que o campo Address Span (Tamanho) esteja configurado corretamente para 4 MBytes (4194304 bytes).

3. Atenção à Geometria de Setores da S29AL032D
Você mencionou que consegue endereçar corretamente os primeiros "16KB". É necessário ter muito cuidado ao avançar para os próximos endereços, pois os setores dessa memória não possuem tamanho uniforme.

O datasheet da memória S29AL032D informa que ela possui uma arquitetura de setores flexível. 

Em modelos de Boot Sector (com configurações de top ou bottom boot block disponíveis), a memória apresenta setores de tamanhos diferentes. 

O componente pode contar com oito setores menores de 8 KBytes e sessenta e três setores de 64 KBytes. 

Por exemplo, no modelo de Bottom Boot (Modelo 04), os primeiros oito setores (SA0 a SA7) possuem 8 KBytes cada. 

Após essa região inicial de setores menores, a memória passa a utilizar setores muito maiores de 64 KBytes (32 KWords), a exemplo do setor SA40 e seguintes. 

Se o seu código de controle supõe que a memória cresce indefinidamente em blocos fixos de 16KB ou 8KB e tenta aplicar a operação de Erase somando esses valores fixos, os endereços calculados após a marca de 32KB ou 64KB estarão no meio de um setor maior. O comando CFI de Apagar Setor deve ser enviado (no 6º ciclo de escrita) ao endereço que representa o limite exato de um bloco válido.

Recomendação de próximos passos:
Substitua seus acessos via ponteiro no C pelas macros IOWR_16DIRECT e tente apagar o setor novamente. Caso não funcione, valide imediatamente o mapa de memória configurado na sua árvore do Qsys.

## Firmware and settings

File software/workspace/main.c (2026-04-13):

#include <stdint.h>
#include <stdbool.h>
#include <string.h>
#include <stdio.h>
#include <unistd.h>
#include <stdlib.h>

#include "system.h"
#include "io.h"
#include "altera_avalon_pio_regs.h"
#include "sprites.h"

/* main.c version: 1.0.7 */

/* =========================
 * Display setup
 * ========================= */
#define PHY_W 128        // largura fisica (painel)
#define PHY_H 64         // altura fisica (painel)
#define VIEW_W 64        // largura virtual usada no jogo
#define VIEW_H 128       // altura virtual usada no jogo

#define HUD_LINE_Y 14    // linha divisoria do HUD
#define GAME_TOP_Y 15    // Y do topo da area de jogo
#define GAME_RENDER_Y_OFFSET -1

/* =========================
 * Timing
 * ========================= */
#define MS_TICK_US      1000 // tick base (us)
#define LOGIC_DT_MS     3    // passo fixo da logica (ms)
#define RENDER_DT_MS    6    // intervalo de render (ms)

/* =========================
 * Colors
 * ========================= */
#define RGB(r,g,b)  (uint8_t)(((r)?1:0) | ((g)?2:0) | ((b)?4:0))
#define COLOR_BLACK 0
#define COLOR_WHITE 7
#define COLOR_RED 1

/* =========================
 * River Raid tuning
 * ========================= */
#define RIVER_MIN_W 36          // largura minima do rio (px)
#define RIVER_MAX_W 58          // largura maxima do rio (px)
#define RIVER_STATIC 0          // 1 = margens retas, 0 = rio variavel
#define RIVER_INIT_W ((RIVER_MIN_W + RIVER_MAX_W) / 2)
#define RIVER_STEP_MS 5       // tempo base para descer 1 linha (ms) - velocidade do game = 5 valor ideal sem tremer
#define RIVER_STEP_DELTA_MS 1  // ajuste relativo ao passo atual (ms) 
#define RIVER_SCROLL_PX_BASE 1   // pixels por passo (fixo em 1) - não alterar - 
#define RIVER_STEP_SLEW_MS  1    // quanto ajusta o passo por tick (ms) - 
#define RIVER_DRAW_ENABLE 1     // 1 = desenha rio, 0 = desativa para teste
#define OBJECTS_DRAW_ENABLE 1   // 1 = desenha objetos, 0 = desativa para teste

/* =========================
 * Opcoes de teste
 * ========================= */
/* Config estavel sugerida: FORCE_FULL_BLIT=0, RENDER_ON_VSYNC_ONLY=0, SCROLL_SYNC_RENDER=0. */
#define COLLISION_ENABLE 1       // 1 = colisao ativa, 0 = desativa para teste
#define FORCE_FULL_BLIT 0        // 1 = ignora diff e escreve tudo (teste de ghost)
#define RENDER_ON_VSYNC_ONLY 0   // 1 = renderiza somente quando o frame terminou
#define SCROLL_SYNC_RENDER 0     // 1 = aplica scroll no render quando velocidade maxima


#define RIVER_MIN_BASE_MS 1     // limite minimo do passo base (ms) -----------------------------------------------testando
#define DIFFICULTY_STEP_MS 5000 // a cada X ms reduz a velocidade base
#define SPAWN_RAMP_MS 300000     // tempo para aumentar spawn (ms)     (tempo para chegar no máximo)
#define ENEMY_SPAWN_MIN 2      // limite inicial do roll de inimigos -  frequência base do HELICOPTER_SPRITE (OBJ_ENEMY).
#define ENEMY_SPAWN_MAX 24      // limite final do roll de inimigos  - frequência base do HELICOPTER_SPRITE (OBJ_ENEMY).
#define ENEMY_ATARI_MIN 1      // limite inicial do roll de heli ATARI - frequência base do HELICOPTER_ATARI (OBJ_HELI_ATARI).
#define ENEMY_ATARI_MAX 10     // limite final do roll de heli ATARI - frequência base do HELICOPTER_ATARI (OBJ_HELI_ATARI).
#define PLANE_SPAWN_MIN 2     // limite inicial do roll de avioes - Quanto menor esse número, menos aviões aparecem.
#define PLANE_SPAWN_MAX 20   // 176     // limite final do roll de avioes
#define BOAT_MIN_Y_GAP 10       // espaco minimo vertical entre barcos (px)
#define FLYING_SPAWN_Y_MARGIN 8 // margem acima do jogador para spawn de objetos voadores (px)

#define PLAYER_W 10             // largura maxima do jogador (px)
#define PLAYER_H 14             // altura maxima do jogador (px)
#define PLAYER_HIT_W 8          // largura do hitbox do jogador (px)
#define PLAYER_HIT_H 12         // altura do hitbox do jogador (px)
#define PLAYER_HIT_X_OFF 1      // deslocamento X do hitbox do jogador (px)
#define PLAYER_HIT_Y_OFF 1      // deslocamento Y do hitbox do jogador (px)
#define PLAYER_STRAIGHT_W 10    // largura da nave reta (px)
#define PLAYER_STRAIGHT_H 14    // altura da nave reta (px)
#define PLAYER_TURN_W 10        // largura da nave virando (px)
#define PLAYER_TURN_H 14        // altura da nave virando (px)
#define PLAYER_Y (VIEW_H - PLAYER_H - 2) // Y da base do jogador
#define PLAYER_MOVE_MS 1        // tempo de interpolacao do movimento (ms) - valor maior deixa mais arrastado
#define PLAYER_SHOT_MS 10      // periodo base do tiro continuo (ms)
#define PLAYER_SHOT_MIN_MS 5   // periodo minimo do tiro continuo (ms)
#define PLAYER_SHOT_ACCEL_MS 10 // tempo para acelerar o tiro (ms)
#define PLAYER_SHOT_STEP_MS 5  // reducao do periodo a cada acel (ms)

#define NUM_LIVES 5

#define DAS_DELAY_MS 12        // atraso inicial do DAS (ms)
#define DAS_SPEED_MS 5         // repeticao do DAS (ms)
#define DIAG_STEP_EVERY 40 //10       // sobe 1px a cada N passos laterais

#define BULLET_SPEED_PX 3        // velocidade do tiro do jogador (px/tick)
#define PLAYER_BULLETS 8         // maximo de tiros do jogador simultaneos

#define ENEMY_MAX 5              // maximo de inimigos simultaneos
#define ENEMY_W 14               // largura do inimigo (px)
#define ENEMY_H 7                // altura do inimigo (px)
#define HELI_HIT_W 10            // largura do hitbox do helicoptero (px)
#define HELI_HIT_H 6             // altura do hitbox do helicoptero (px)
#define HELI_HIT_X_OFF 2         // deslocamento X do hitbox do helicoptero (px)
#define HELI_HIT_Y_OFF 0         // deslocamento Y do hitbox do helicoptero (px)
#define PLANE_HIT_W 10           // largura do hitbox do aviao (px)
#define PLANE_HIT_H 6            // altura do hitbox do aviao (px)
#define PLANE_HIT_X_OFF 2        // deslocamento X do hitbox do aviao (px)
#define PLANE_HIT_Y_OFF 0        // deslocamento Y do hitbox do aviao (px)
#define HELI_ATARI_W 16          // largura do helicoptero ATARI (px)
#define HELI_ATARI_H 10          // altura do helicoptero ATARI (px)

#define BOAT_SMALL_W 14          // largura do porta-avioes (px)
#define BOAT_SMALL_H 6           // altura do porta-avioes (px)
#define DESTROYER_W 32           // largura do destroyer (px)
#define DESTROYER_H 6            // altura do destroyer (px)
#define PLANE_W 14               // largura do aviao (px)
#define PLANE_H 6                // altura do aviao (px)
#define EXPLOSION_W 10           // largura da explosao (px)
#define EXPLOSION_H 8            // altura da explosao (px)
#define EXPLOSION2_W 15          // largura da explosao 2 (px)
#define EXPLOSION2_H 11          // altura da explosao 2 (px)

#define BRIDGE_SIDE_W 32         // largura do sprite lateral da ponte (px)
#define BRIDGE_SIDE_H 12         // altura do sprite lateral da ponte (px)
#define BRIDGE_H BRIDGE_SIDE_H   // altura da ponte (px)
#define BRIDGE_OPEN_W 33         // largura da abertura da ponte (px)
#define BRIDGE_EFFECT_H 4        // alcance vertical do afunilamento (px)
#define BRIDGE_COLLISION_H 1     // alcance vertical do afunilamento para colisao (px)
#define BRIDGE_VEG_INSET 20       // quanto a vegetacao invade o rio (px)
#define BRIDGE_VEG_DEPTH 20       // profundidade visivel da vegetacao no rio (px)
#define BRIDGE_VEG_UP 25          // altura acima da ponte com vegetacao (px)
#define BRIDGE_VEG_DOWN 30        // altura abaixo da ponte com vegetacao (px)

#define RESPAWN_PORTAL_H 18       // altura do portal de respawn (px)
#define RESPAWN_PORTAL_NARROW_H 6 // altura da garganta do portal (px)
#define RESPAWN_PORTAL_FLARE_H 8  // altura do alargamento do portal (px)
#define RESPAWN_PORTAL_NARROW_W 30 // largura estreita do portal (px)
#define RESPAWN_PORTAL_BELOW_H 64  // altura do portal abaixo do jogador (px)

#define FUEL_MAX 100             // combustivel maximo
#define FUEL_DEC_MS 90           // tempo para consumir 1 unidade de combustivel (ms)
#define FUEL_PICKUP 25           // combustivel ganho ao coletar
#define FUEL_W 10                // largura do combustivel (px)
#define FUEL_H 24                // altura do combustivel (px)
#define HUD_FUEL_W 27            // largura do HUD fuel (px)
#define HUD_FUEL_H 10            // altura do HUD fuel (px)

#define SCORE_ENEMY 10
#define SCORE_BOAT  20
#define SCORE_PLANE 30
#define SCORE_BRIDGE 50

#define EXPLOSION_MS 50
#define PLAYER_EXPLOSION_MS 80
#define DESTROYER_EXPLOSION_MS 90

/* =========================
 * Fonts
 * ========================= */
static const uint16_t FONT_NUM[10] = {
    0x7B6F, 0x2C97, 0x73E7, 0x73CF, 0x5BC9,
    0x79CF, 0x79EF, 0x7249, 0x7BEF, 0x7BCF
};

static const uint8_t FONT_VHDL[7][7] = {
    {0x0E, 0x11, 0x10, 0x13, 0x11, 0x11, 0x0E},
    {0x0E, 0x11, 0x11, 0x1F, 0x11, 0x11, 0x11},
    {0x11, 0x1B, 0x15, 0x11, 0x11, 0x11, 0x11},
    {0x1F, 0x10, 0x10, 0x1F, 0x10, 0x10, 0x1F},
    {0x0E, 0x11, 0x11, 0x11, 0x11, 0x11, 0x0E},
    {0x11, 0x11, 0x11, 0x11, 0x0A, 0x0A, 0x04},
    {0x1E, 0x11, 0x11, 0x1E, 0x14, 0x12, 0x11}
};

static const uint8_t GAMMA_TABLE[256] = {
    0,   0,   0,   0,   0,   0,   0,   0,   0,   0,   1,   1,   1,   1,   1,   1,
    1,   1,   2,   2,   2,   2,   2,   2,   3,   3,   3,   3,   4,   4,   4,   4,
    5,   5,   5,   5,   6,   6,   6,   7,   7,   7,   8,   8,   8,   9,   9,   9,
   10,  10,  11,  11,  12,  12,  13,  13,  14,  14,  15,  15,  16,  16,  17,  18,
   18,  19,  19,  20,  21,  21,  22,  22,  23,  24,  25,  25,  26,  27,  27,  28,
   29,  30,  31,  31,  32,  33,  34,  35,  36,  37,  38,  39,  40,  41,  42,  43,
   44,  45,  46,  47,  48,  50,  51,  52,  53,  54,  55,  57,  58,  59,  60,  62,
   63,  64,  66,  67,  68,  70,  71,  72,  74,  75,  77,  78,  80,  81,  83,  84,
   86,  88,  89,  91,  92,  94,  96,  97,  99, 101, 103, 104, 106, 108, 110, 112,
  114, 116, 118, 120, 122, 124, 126, 128, 130, 132, 134, 136, 138, 140, 143, 145,
  147, 149, 152, 154, 156, 159, 161, 163, 166, 168, 171, 173, 176, 178, 181, 183,
  186, 189, 191, 194, 197, 199, 202, 205, 208, 210, 213, 216, 219, 222, 225, 228,
  231, 234, 237, 240, 243, 246, 250, 253, 255, 255, 255, 255, 255, 255, 255, 255,
  255, 255, 255, 255, 255, 255, 255, 255, 255, 255, 255, 255, 255, 255, 255, 255,
  255, 255, 255, 255, 255, 255, 255, 255, 255, 255, 255, 255, 255, 255, 255, 255,
  255, 255, 255, 255, 255, 255, 255, 255, 255, 255, 255, 255, 255, 255, 255, 255
};

static uint8_t viewbuf[VIEW_W * VIEW_H];
static uint8_t prevbuf[VIEW_W * VIEW_H];
static uint16_t base_addr_xv[VIEW_W];

typedef enum { STATE_PLAYING, STATE_GAME_OVER_FADE, STATE_GAME_OVER } game_state_t;
static game_state_t current_state = STATE_PLAYING;

typedef struct { int x; int y; int active; } bullet_t;

typedef enum { OBJ_ENEMY, OBJ_HELI_ATARI, OBJ_FUEL, OBJ_BOAT_SMALL, OBJ_DESTROYER, OBJ_PLANE, OBJ_BRIDGE } obj_type_t;

typedef struct {
    int x;
    int y;
    int vx;
    int w;
    int h;
    obj_type_t type;
    int destroyed;
    int explosion_ms;
    uint8_t explosion_kind;
    int active;
} obj_t;

static void update_explosions(void);
static void draw_explosion_clipped(int x0, int y0);
static void draw_explosion2_clipped(int x0, int y0);

static int river_left[VIEW_H];
static int river_right[VIEW_H];
static int river_head = 0;
static int river_center = VIEW_W / 2;
static int river_width = 30;

static obj_t objects[ENEMY_MAX];
static bullet_t player_bullets[PLAYER_BULLETS];
static uint8_t enemy_turn_cd[ENEMY_MAX];

static int player_x = 0;
static int player_y = 0;
static int player_prev_x = 0;
static int player_prev_y = 0;
static int player_dir = 0;
static uint8_t heli_frame = 0;
static uint32_t heli_anim_acc_ms = 0;
static uint32_t player_move_acc_ms = 0;
static uint32_t player_shot_acc_ms = 0;
static uint32_t player_shot_hold_ms = 0;
static int timer_das_l = 0;
static int timer_das_r = 0;
static int timer_das_u = 0;
static int timer_das_d = 0;
static uint8_t diag_step = 0;

static uint32_t scroll_acc_ms = 0;
static uint32_t river_scroll_limit_ms = RIVER_STEP_MS;
static uint32_t river_scroll_target_ms = RIVER_STEP_MS;
static uint32_t river_scroll_base_ms = RIVER_STEP_MS;
static uint32_t fuel_acc_ms = 0;
static uint8_t fuel = FUEL_MAX;
static uint32_t score = 0;
static uint8_t lives = NUM_LIVES;

static uint8_t spawn_cd_enemy = 0;
static uint8_t spawn_cd_fuel = 0;
static uint8_t spawn_cd_boat = 0;
static uint8_t spawn_cd_plane = 0;
static uint8_t spawn_cd_bridge = 0;
static uint8_t enemy_atari_toggle = 0;
static uint32_t respawn_delay_ms = 0;
static uint8_t respawn_pending = 0;
static uint8_t player_hidden = 0;
static uint32_t player_explosion_ms = 0;

static uint16_t lfsr = 0xA5A5;
static uint32_t ms_global = 0;
static uint32_t game_time_ms = 0;

static uint8_t input_locked = 0;
static uint8_t game_started = 0;
static uint8_t prev_any_key = 0;

static int river_speed_dir = 0;
static uint8_t scroll_step_pending = 0;

/* =========================
 * Video sync
 * ========================= */
#define LED_STATUS_ADDR 8193
#define LED_FRAME_DONE  0x01

static inline void wait_frame(void) {
    while ((IORD_8DIRECT(LED_MATRIX_AVALON_0_BASE, LED_STATUS_ADDR) & LED_FRAME_DONE) == 0)
        ;
    IOWR_8DIRECT(LED_MATRIX_AVALON_0_BASE, LED_STATUS_ADDR, LED_FRAME_DONE);
}

static inline int frame_done_pending(void) {
    if ((IORD_8DIRECT(LED_MATRIX_AVALON_0_BASE, LED_STATUS_ADDR) & LED_FRAME_DONE) == 0)
        return 0;
    IOWR_8DIRECT(LED_MATRIX_AVALON_0_BASE, LED_STATUS_ADDR, LED_FRAME_DONE);
    return 1;
}

/* =========================
 * Brightness control
 * ========================= */
#define LED_BRIGHTNESS_OFFSET 8192
#define DEFAULT_BRIGHTNESS 100
#define PS2_BASE PS2_INTERFACE_0_BASE

static uint8_t fade_brightness = DEFAULT_BRIGHTNESS;
static uint32_t fade_acc_ms = 0;

#define FADE_STEP_MS    5
#define FADE_STEP_VAL   1

/* =========================
 * Input
 * ========================= */
#define PS2_VALID_MASK    (1u << 31)
#define PS2_RELEASED_MASK (1u << 30)
#define PS2_EXTENDED_MASK (1u << 29)
#define PS2_CODE_MASK     0xFF

#define K_RIGHT   0x01
#define K_DOWN    0x02
#define K_ROT     0x04
#define K_LEFT    0x08
#define K_SPACE   0x10

static volatile uint8_t kb_held     = 0;
static volatile uint8_t kb_pressed  = 0;
static volatile uint8_t ps2_held    = 0;
static uint8_t ps2_pending_release = 0;
static uint8_t ps2_pending_extended = 0;

/* =========================
 * Helpers
 * ========================= */
static void set_display_brightness(uint8_t level);

static void lfsr_step(void) {
    uint16_t bit = (uint16_t)(((lfsr >> 15) ^ (lfsr >> 13)) & 1);
    lfsr = (uint16_t)((lfsr << 1) | bit);
}

static int font_get_bit(const uint16_t *font_table, int glyph_idx, int x, int y) {
    if (x < 0 || x > 2 || y < 0 || y > 4) return 0;
    uint16_t v = font_table[glyph_idx];
    int bit_idx = 14 - (y * 3 + x);
    return (v >> bit_idx) & 1;
}

static void draw_digit_tall(int digit, int start_x, int start_y, uint8_t color) {
    int gx, gy;
    for (gy = 0; gy < 5; gy++) {
        for (gx = 0; gx < 3; gx++) {
            if (font_get_bit(FONT_NUM, digit, gx, gy)) {
                viewbuf[(start_y + (gy * 2)) * VIEW_W + (start_x + gx)] = color;
                viewbuf[(start_y + (gy * 2) + 1) * VIEW_W + (start_x + gx)] = color;
            }
        }
    }
}

static void view_put(int xv, int yv, uint8_t rgb) {
    if ((unsigned)xv >= VIEW_W || (unsigned)yv >= VIEW_H) return;
    viewbuf[yv * VIEW_W + xv] = (uint8_t)(rgb & 7);
}

static void draw_vhdl_char(int char_idx, int start_x, int start_y, uint8_t color) {
    int row, col;
    for (row = 0; row < 7; row++) {
        uint8_t line = FONT_VHDL[char_idx][row];
        for (col = 0; col < 5; col++) {
            if ((line >> (4 - col)) & 1) {
                int px = start_x + (col * 2);
                int py = start_y + (row * 2);
                view_put(px,   py,   color);
                view_put(px+1, py,   color);
                view_put(px,   py+1, color);
                view_put(px+1, py+1, color);
            }
        }
    }
}

static void view_clear(void) {
    memset(viewbuf, 0, sizeof(viewbuf));
}

static int get_scroll_offset_px(void)
{
    if (river_scroll_limit_ms == 0) return 0;
    int offset_y_px = (int)((scroll_acc_ms * RIVER_SCROLL_PX_BASE) / river_scroll_limit_ms);
    if (offset_y_px >= RIVER_SCROLL_PX_BASE) offset_y_px = RIVER_SCROLL_PX_BASE - 1;
    if (offset_y_px < 0) offset_y_px = 0;
    return offset_y_px;
}

static void draw_rect(int x0, int y0, int w, int h, uint8_t color)
{
    for (int y = 0; y < h; y++) {
        int yy = y0 + y;
        if (yy < 0 || yy >= VIEW_H) continue;
        int row = yy * VIEW_W;
        for (int x = 0; x < w; x++) {
            int xx = x0 + x;
            if (xx < 0 || xx >= VIEW_W) continue;
            viewbuf[row + xx] = color;
        }
    }
}

static void init_panel_lut_small(void)
{
    for (int xv = 0; xv < VIEW_W; xv++) {
        int yp = 63 - xv;
        uint32_t base;
        if (yp < 32) base = (uint32_t)(yp * 128);
        else         base = 4096u + (uint32_t)((yp - 32) * 128);
        base_addr_xv[xv] = (uint16_t)base;
    }
    memset(prevbuf, 0xFF, sizeof(prevbuf));
}

static void blit_diff_to_panel_small_lut(void)
{
    for (int yv = 0; yv < VIEW_H; yv++) {
        uint16_t xp = (uint16_t)yv;
        int row = yv * VIEW_W;
        for (int xv = 0; xv < VIEW_W; xv++) {
            int i = row + xv;
            uint8_t v = (uint8_t)(viewbuf[i] & 7);
            if (yv < GAME_TOP_Y) {
                prevbuf[i] = v;
                uint16_t addr = (uint16_t)(base_addr_xv[xv] + xp);
                IOWR_8DIRECT(LED_MATRIX_AVALON_0_BASE, addr, v);
                continue;
            }
            if (!FORCE_FULL_BLIT && v == prevbuf[i]) continue;
            prevbuf[i] = v;

            uint16_t addr = (uint16_t)(base_addr_xv[xv] + xp);
            IOWR_8DIRECT(LED_MATRIX_AVALON_0_BASE, addr, v);
        }
    }
}

static void set_display_brightness(uint8_t level)
{
    uint8_t corrected_pwm = GAMMA_TABLE[level];
    IOWR_8DIRECT(LED_MATRIX_AVALON_0_BASE, LED_BRIGHTNESS_OFFSET, corrected_pwm);
}

/* =========================
 * Input handling
 * ========================= */
static void ps2_update_held(uint8_t mask, int is_released) {
    uint8_t before = kb_held;
    if (is_released) ps2_held &= ~mask; else ps2_held |= mask;
    if (!is_released && !(before & mask)) kb_pressed |= mask;
}
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
int main(void)
{
    uint32_t last_logic  = ms_global;
    uint32_t last_render = ms_global;
    uint32_t acc_logic   = 0;

    set_display_brightness(DEFAULT_BRIGHTNESS);
    printf("River Raid - PS2 + PIO\n");

    init_panel_lut_small();
    reset_full_game();

    static uint8_t game_over_armed = 0;

    while (1)
    {
        usleep(MS_TICK_US);
        ms_global++;
        lfsr_step();
        handle_input_merge();

        const uint32_t MAX_DT_MS = 40;
        const uint32_t MAX_STEPS = 8;

        uint32_t dt = ms_global - last_logic;
        if (dt > 0)
        {
            last_logic = ms_global;
            if (dt > MAX_DT_MS) dt = MAX_DT_MS;
            acc_logic += dt;

            uint32_t steps = 0;
            while (acc_logic >= LOGIC_DT_MS && steps < MAX_STEPS)
            {
                acc_logic -= LOGIC_DT_MS;
                steps++;

                uint8_t pressed_snapshot = kb_pressed;
                kb_pressed = 0;

                switch (current_state)
                {
                    case STATE_PLAYING:
                        update_play_state(pressed_snapshot, kb_held);
                        prev_any_key = (kb_held != 0);
                        break;

                    case STATE_GAME_OVER_FADE:
                        if (update_game_over_fade()) {
                            prev_any_key = 1;
                        }
                        break;

                    case STATE_GAME_OVER:
                        if (prev_any_key && kb_held == 0) prev_any_key = 0;
                        if (!prev_any_key && kb_held != 0) {
                            reset_full_game();
                            current_state = STATE_PLAYING;
                            game_over_armed = 0;
                        }
                        if (kb_held != 0) prev_any_key = 1;
                        break;
                }
            }

            if (steps == MAX_STEPS)
                acc_logic = 0;
        }

        int render_due = 0;
#if RENDER_ON_VSYNC_ONLY
        render_due = frame_done_pending();
#else
        render_due = ((ms_global - last_render) >= RENDER_DT_MS);
#endif

        if (render_due)
        {
            last_render = ms_global;

            if (current_state == STATE_GAME_OVER_FADE)
                continue;

            uint32_t render_start = ms_global;
            (void)render_start;

            if (SCROLL_SYNC_RENDER && river_scroll_limit_ms <= 1 && scroll_step_pending) {
                scroll_step_pending = 0;
                river_scroll_step();
                objects_scroll_step();
            }

            view_clear();

            if (current_state == STATE_PLAYING)
            {
                render_play_screen();
            }
            else if (current_state == STATE_GAME_OVER)
            {
                int game_ids[] = {0, 1, 2, 3};
                for (int i = 0; i < 4; i++)
                    draw_vhdl_char(game_ids[i], 8 + (i * 12), 45, COLOR_WHITE);

                int over_ids[] = {4, 5, 3, 6};
                for (int i = 0; i < 4; i++)
                    draw_vhdl_char(over_ids[i], 8 + (i * 12), 65, COLOR_WHITE);

                if (!game_over_armed) {
                    wait_frame();
                    blit_diff_to_panel_small_lut();
                    set_display_brightness(DEFAULT_BRIGHTNESS);
                    game_over_armed = 1;
                }
            }

            if (!RENDER_ON_VSYNC_ONLY) {
                wait_frame();
            }
            blit_diff_to_panel_small_lut();
        }
    }
}

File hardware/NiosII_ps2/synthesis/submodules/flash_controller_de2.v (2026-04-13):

module flash_controller_de2 (
    output reg [7:0]  oDATA,
    input      [7:0]  iDATA,
    input      [21:0] iADDR,
    input      [2:0]  iCMD,
    output            oReady,
    input             iStart,
    input             iCLK,
    input             iRST_n,
    inout      [7:0]  FL_DQ,
    output reg [21:0] FL_ADDR,
    output            FL_WE_n,
    output            FL_CE_n,
    output            FL_OE_n,
    output            FL_RST_n
);

reg [21:0] Cont_Finish;
reg [21:0] CMD_Period;
reg [7:0]  mDATA;
reg [10:0] Cont_DIV;
reg [10:0] WE_CLK_Delay;
reg [10:0] Start_Delay;
reg [3:0]  ST;
reg        mCLK;
reg        mStart;
reg        preStart;
reg        pre_mCLK;
reg        mACT;
reg        mFinish;
reg [2:0]  r_CMD;
reg [21:0] r_ADDR;
reg [7:0]  r_DATA;

wire WE_CLK;

`include "flash_command.vh"

parameter PER_READ      = 8;
parameter PER_WRITE     = 5;
parameter PER_BLK_ERA   = 160000;
parameter PER_SEC_ERA   = 160000;
parameter PER_CHP_ERA   = 640000;
parameter PER_ENTRY_ID  = 32;
parameter PER_RESET     = 16;

parameter IDEL          = 0;
parameter P1            = 1;
parameter P2            = 2;
parameter P3            = 3;
parameter P4            = 4;
parameter P5            = 5;
parameter P3_PRG        = 6;
parameter P3_DEV        = 7;
parameter P4_PRG        = 8;
parameter P6_BLK_ERA    = 9;
parameter P6_SEC_ERA    = 10;
parameter P6_CHP_ERA    = 11;
parameter READ          = 12;
parameter RESET         = 13;
parameter CLK_Divide    = 8;

assign FL_DQ   = FL_OE_n ? mDATA : 8'bzzzzzzzz;
assign FL_OE_n = (ST == READ) ? 1'b0 : 1'b1;
assign FL_CE_n = (ST == IDEL) ? 1'b1 : 1'b0;
assign FL_WE_n = (ST == IDEL) ? 1'b1 :
                 (ST == READ) ? 1'b1 : WE_CLK;
assign FL_RST_n = 1'b1;
assign oReady = mStart ? 1'b0 : mFinish;

always @(posedge iCLK or negedge iRST_n) begin
    if (!iRST_n) begin
        Cont_DIV <= 0;
        mCLK <= 0;
    end else begin
        Cont_DIV <= Cont_DIV + 1'b1;
        mCLK <= Cont_DIV[CLK_Divide >> 2];
    end
end

always @(posedge iCLK or negedge iRST_n) begin
    if (!iRST_n)
        WE_CLK_Delay <= 0;
    else
        WE_CLK_Delay <= {WE_CLK_Delay[9:0], Cont_DIV[CLK_Divide >> 2]};
end

assign WE_CLK = (CLK_Divide == 4) ? ~WE_CLK_Delay[3] :
                (CLK_Divide == 8) ? ~WE_CLK_Delay[4] :
                                    ~WE_CLK_Delay[10];

always @(posedge iCLK or negedge iRST_n) begin
    if (!iRST_n) begin
        mStart <= 0;
        Start_Delay <= 0;
        preStart <= 0;
        pre_mCLK <= 0;
        mACT <= 0;
    end else begin
        if ({pre_mCLK, mCLK} == 2'b01)
            mACT <= 1'b1;
        else
            mACT <= 1'b0;
        pre_mCLK <= mCLK;

        if ({preStart, iStart} == 2'b01) begin
            mStart <= 1'b1;
            Start_Delay <= 0;
            r_CMD <= iCMD;
            r_ADDR <= iADDR;
            r_DATA <= iDATA;
        end else begin
            if (Start_Delay < CLK_Divide)
                Start_Delay <= Start_Delay + 1'b1;
            else
                mStart <= 1'b0;
        end
        preStart <= iStart;
    end
end

always @(posedge iCLK or negedge iRST_n) begin
    if (!iRST_n)
        oDATA <= 8'h00;
    else if (mACT && (ST == READ))
        oDATA <= FL_DQ;
end

always @(posedge iCLK or negedge iRST_n) begin
    if (!iRST_n)
        ST <= IDEL;
    else if (mACT) begin
        if (mStart) begin
            case (r_CMD)
                CMD_READ     : ST <= READ;
                CMD_WRITE    : ST <= P1;
                CMD_BLK_ERA  : ST <= P1;
                CMD_SEC_ERA  : ST <= P1;
                CMD_CHP_ERA  : ST <= P1;
                CMD_ENTRY_ID : ST <= P1;
                CMD_RESET    : ST <= RESET;
                CMD_RAW_WRITE: ST <= P4_PRG;
                default      : ST <= IDEL;
            endcase
        end else begin
            case (ST)
                IDEL       : ST <= IDEL;
                P1         : ST <= P2;
                P2         : begin
                    case (r_CMD)
                        CMD_WRITE     : ST <= P3_PRG;
                        CMD_ENTRY_ID  : ST <= P3_DEV;
                        default       : ST <= P3;
                    endcase
                end
                P3         : ST <= P4;
                P4         : ST <= P5;
                P5         : begin
                    case (r_CMD)
                        CMD_BLK_ERA : ST <= P6_BLK_ERA;
                        CMD_SEC_ERA : ST <= P6_SEC_ERA;
                        CMD_CHP_ERA : ST <= P6_CHP_ERA;
                        default     : ST <= IDEL;
                    endcase
                end
                P3_PRG     : ST <= P4_PRG;
                P3_DEV     : ST <= IDEL;
                P4_PRG     : ST <= IDEL;
                P6_BLK_ERA : ST <= IDEL;
                P6_SEC_ERA : ST <= IDEL;
                P6_CHP_ERA : ST <= IDEL;
                READ       : ST <= IDEL;
                RESET      : ST <= IDEL;
                default    : ST <= IDEL;
            endcase
        end
    end
end

always @(posedge iCLK or negedge iRST_n) begin
    if (!iRST_n) begin
        mFinish <= 0;
        Cont_Finish <= 0;
    end else if (mACT) begin
        if (mStart) begin
            mFinish <= 1'b0;
            Cont_Finish <= 0;
        end else begin
            if (Cont_Finish < CMD_Period)
                Cont_Finish <= Cont_Finish + 1'b1;
            else
                mFinish <= 1'b1;
        end
    end
end

always @(*) begin
    case (r_CMD)
        CMD_READ     : CMD_Period = PER_READ - 1;
        CMD_WRITE    : CMD_Period = PER_WRITE - 1;
        CMD_BLK_ERA  : CMD_Period = PER_BLK_ERA - 1;
        CMD_SEC_ERA  : CMD_Period = PER_SEC_ERA - 1;
        CMD_CHP_ERA  : CMD_Period = PER_CHP_ERA - 1;
        CMD_ENTRY_ID : CMD_Period = PER_ENTRY_ID - 1;
        CMD_RESET    : CMD_Period = PER_RESET - 1;
        CMD_RAW_WRITE: CMD_Period = PER_WRITE - 1;
        default      : CMD_Period = 0;
    endcase
end
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

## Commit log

2026-04-13 Initial commit: MEU_CONSOLE_FPGA_DE0_SD
    [stp1.stp, stp1_auto_stripped.stp, stp2.stp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]
2026-04-13 Docs: refresh README and fix outdated project references
    [alt_sys_init.c, system.h]
2026-04-13 Remove I2C audio integration note from README
    Removed mention of integrated I2C audio in the README.
2026-04-13 Games: add UART control to Arkanoid and Pong
